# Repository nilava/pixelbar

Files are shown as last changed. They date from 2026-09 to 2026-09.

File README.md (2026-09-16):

# Pixelbar

An 8×24 WS2812B desk panel driven by an ESP32-C3, built as an open alternative
to a Busy Bar: it shows your status to the room, runs a focus timer, keeps the
time, and takes input from a rotary encoder, three hidden touch zones, and a
web page on your phone.

The panel is three 65 mm 8×8 WS2812B boards butted edge to edge inside a
snap-fit printed case, behind a per-LED light grid and a diffuser. It joins
your network through a setup network of its own, so nothing is compiled in and
no credential ever enters the source tree.

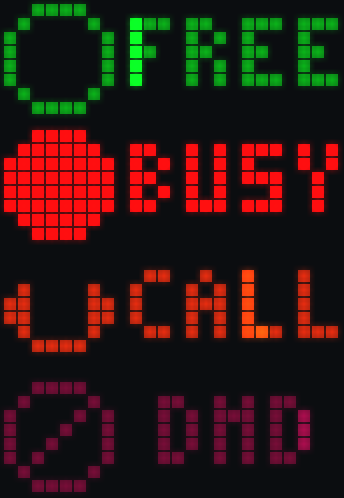
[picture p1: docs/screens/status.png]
status screens


## Status

**It works, on real hardware.** The panel runs at a measured 100 fps, joins
WiFi through its own setup portal, keeps the right time over SNTP, serves a web
page you can drive it from, and remembers everything you change across a power
cut. The encoder is wired and the whole screen tree is navigable from it.

| | |
| --- | --- |
| Display, input, screens, settings | done, on hardware |
| WiFi, setup portal, SNTP, web page | done, on hardware |
| LED output over SPI + GDMA | done — see *Why not RMT* below |
| Touch pads | written and host-tested; the TTP223s are not soldered yet |
| Accelerometer | not started; the MPU-6050 is not fitted |
| OTA, Mac mic-detect helper, Slack and calendar | not started |

28,807 assertions run on a laptop with no hardware and no ESP-IDF. The image is
at 49% of its 1.66 MB slot.

## Controls and screens

Three touch zones sit under the top edge, marked by printed dimples, and the
encoder knob is on the top edge at the right.

| Input | Action |
| --- | --- |
| Knob, turn | The value on this screen, or the view cycle at rest |
| Knob, press | Go in: open a menu entry, accept a value, claim a status |
| Knob, hold | Come back out, one level at a time |
| Knob, double-press | Straight back to the home view |
| Left zone, tap | FREE ↔ BUSY |
| Left zone, double-tap | CALL |
| Left zone, hold | CALL |
| Middle zone, tap | Start or pause the focus timer |
| Middle zone, hold | Reset the timer to its set length |
| Right zone, tap | Next view |
| Right zone, hold | DND on or off |
| Left and right together | Sleep or wake |
| Swipe across the zones | Next or previous view |

The four home views the knob cycles are **status**, **clock**, **timer** and
**scene**. The touch rows are written and tested but the pads are not soldered
yet, so today they are reachable only from the web page, which drives them as
pad *levels* rather than as events — the gesture recogniser sees exactly what a
finger would produce.

**Press goes in, hold comes out**, at every level. One rule the whole way down
means there is always a way back that does not depend on remembering how deep
you are. Turning the knob while pressing it used to adjust brightness from
anywhere; that is gone, because on a KY-040 the push switch shares its ground
with the rotary contacts, so an ordinary turn kept being read as the modifier
and the panel fought itself. Two gestures competing for one movement is worse
than one gesture and a menu.

A tap never waits to find out whether it is going to become a double tap:
holding it back for the 280 ms that would take puts the delay on the most-used
gesture on the device. The first tap fires at once and the second *supersedes*
it, which works because the actions behind them are assignments — BUSY, then
CALL — rather than steps.

Telling a chord from a swipe is the awkward one, because a finger dragged
across the pads lights two at once as well. Timing cannot separate them: for the
first hundred milliseconds a brisk swipe and a two-finger press are identical.
What separates them is that a chord is *held* and a drag is not.

The status words are each 23 px wide in the proportional font, so they sit
still and centred rather than scrolling. Anything wider than the panel scrolls
automatically.

An 8x8 icon, a one pixel gutter, and the label in a 3x5 mini font: exactly 24
columns, so a status word never scrolls. FREE is an open ring and BUSY is the
same ring filled in, which is what makes the change between them read as the
ring solidifying.

That layout has 15 columns for the word, and AWAY, FOCUS, LUNCH and MEET are
wider than that. Rather than scroll them, those statuses drop the icon and take
the whole panel as a **badge**: a filled field in the status colour with the
word cut out of it in black. Colour carries the meaning, so no picture is
needed, and it reads from much further away because the lit area is three times
larger. The two layouts turn over into each other without either knowing which
the other is.

The badge fill is held below full value on purpose. A full-width field lights
about 150 LEDs where the icon layout lights 48, and at full value the brighter
statuses draw past the 2500 mA cap — which the renderer would handle by scaling
*those statuses only*, so changing status would visibly change how bright the
panel is.

| | |
| --- | --- |
| boot | disk |
| free | call |
| focus | lunch |
| menu | status picker |
| timer | colour picker |

Holding the knob opens a menu, which scrolls like the view cycle does. The
status picker shows each status *as the panel would show it* rather than as a
row about it, so what you are scrolling through is a preview of what the room
will see.

Elements change in place rather than moving across the panel. A digit turns
over like the face of a counter wheel — both faces on screen for the whole
turn, the outgoing one foreshortening and riding away from the axis while the
incoming one rises into it, which is the projection of a cylinder and is drawn
as one. An icon and its label hand over by collapsing into themselves while the
next pair grows out of the same spot.

Everything moves. Icons breathe, CALL animates its handset and pulses harder
because it is the one status that must interrupt you, the clock's second hand
walks the panel's 60-pixel perimeter, timer digits roll, bars glide to their
targets, and the colour picker has a specular band travelling its ramp.

## Settings

The menu is the settings tree, scrolled like a record. Ten groups, and
everything the device stores or is paired with is reachable from the knob.

| Group | Settings |
| --- | --- |
| **STAT** | jumps straight to the status picker — a shortcut, not a group |
| **DISP** | brightness, accent hue, flip, sleep-after, current cap |
| **TIME** | work minutes, rest minutes, sets, auto-continue |
| **IDLE** | which ambient scene: solid, rainbow, plasma, sparkle |
| **TILT** | motion gestures on/off, lay-flat-to-sleep |
| **TAP** | touch lock |
| **CLCK** | 12 or 24 hour |
| **WIFI** | **IP** shows the address, **DROP** forgets the network |
| **HOST** | **ADD** opens a pairing window, **LIST** shows who is paired, **DROP** forgets them all |
| **PLAY** | the media remote — jumps straight to it, a shortcut not a group |
| **SYS** | **WIPE** — tokens, bonds and network, then a restart into setup |

DROP forgets one thing and WIPE forgets everything; the group says what the
thing is. Every one of them asks first, on a screen that opens on *no* — the
knob has no undo.

**PLAY** needs no software at all. The panel advertises a Bluetooth HID
service, so any Mac, iPhone, Windows or Linux machine can pair it as a media
remote from its own Bluetooth settings and never hear the name Pixelbar. On
that screen the knob is a volume dial, pressing it is play/pause, and the three
pads are previous, play/pause and next. The arcs beside the speaker are lit
only while something is actually listening — a volume dial connected to nothing
looks exactly like one that works.

**HOST** is the group worth knowing about. The panel is driven over HTTP by
hosts holding a token, and over Bluetooth by hosts that have bonded; **LIST**
is the one place the device says who those are, by the name each gave when it
paired. **SYS → WIPE** exists because the alternative was an authenticated
request from a host that was already paired — so a panel whose Mac had gone,
been re-imaged, or would not pair had no way back at all.

| | |
| --- | --- |
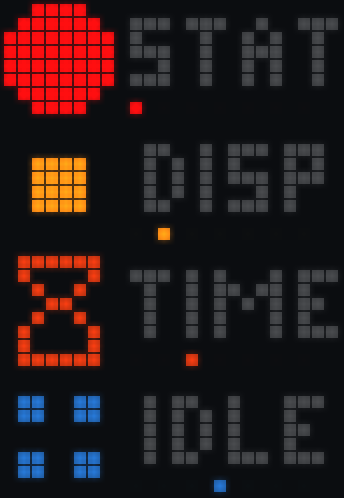
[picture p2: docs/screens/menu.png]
menu
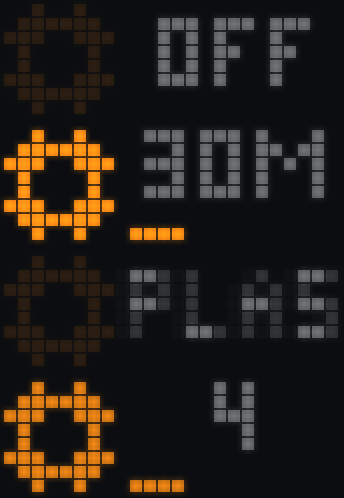
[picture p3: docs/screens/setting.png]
setting
|  |  |

A setting is a row in a table rather than a screen of its own: what it is
called, what it looks like, what kind of value it holds, and an id that one
get/set pair switches on. One generic screen serves toggles, numbers and
choices, because they differ by a few pixels and not by a layout — the value
arrives already rendered as `ON`, `25M` or `PLASMA`, so the drawing layer never
learns what any setting *means*.

Everything is one versioned struct in a single NVS blob: one atomic write, and
a migration is a version check instead of forty defaulted lookups. It is
written once the knob stops moving rather than once per detent.

## Network and setup

Nothing is compiled in. With no credentials stored the device brings up an open
`PIXELBAR-XXXX` network and a captive portal; join it and the setup page opens
by itself.

That last part is two pieces working together. A DNS responder answers every
query with the device's own address, so the phone's connectivity check —
`captive.apple.com`, `connectivitycheck.gstatic.com` — resolves to us; and a
404 handler redirects, which is what the phone recognises as a portal rather
than an internet. Sixty lines of socket code, because the only query worth
parsing is one we have already decided the answer to.

Credentials are stored **only once they have worked**. The device tries them
over the station half of an APSTA mode while the portal is still up, so a typo
is reported back to the page instead of being persisted and locking the device
out of its own setup on the next boot. If a stored network then becomes
unreachable for six attempts — you moved house, the password changed — the
setup network comes back, because the web page needs a network and the panel
cannot type a password.

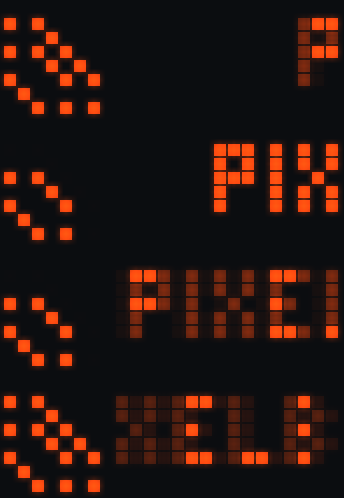
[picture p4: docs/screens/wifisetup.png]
wifi setup


The panel says which of the three it is doing: the network to join, the network
being tried, or the address to visit. All three are one layout — a signal mark
and a marquee — separated by colour and by how fast the arcs climb.

Time comes from SNTP once there is an address. Before the first sync the clock
shows `--:--` rather than midnight: a clock that is confidently wrong is worse
than one that admits it is waiting.

## The web page

One self-contained HTML file, gzipped at build time and linked into the image.
It cannot live in a filesystem partition — the partition table already spends
3.5 MB of a 4 MB part on two OTA slots.

It emulates the touch pads and the knob, sets status and brightness directly,
runs the WiFi setup, and shows what the panel is showing.

```
GET    /                     the page
GET    /api/state            screen, status, timer, brightness, fps, clock
POST   /api/input            pads as levels, knob detents, status, brightness
POST   /api/display/draw     show something; see below
DELETE /api/display/draw     stop showing it
POST   /api/ota              a firmware image; the panel restarts itself
GET    /api/screen           what the panel is showing, as hex RGB
GET    /api/wifi/scan        nearby networks
GET    /api/wifi/status
POST   /api/wifi/connect     {"ssid": "...", "pass": "..."}
POST   /api/wifi/forget
```

### Watching it from elsewhere

`GET /api/screen` returns the framebuffer as 192 hex RGB triples, and the web
page draws it into a canvas about ten times a second. This panel was debugged
by photograph three times in one evening; that is what it is for.

They are the framebuffer's own colours, before gamma and the current cap —
what the screen *means* rather than what the LEDs receive. The wire bytes are
already covered by the preview tool and the map test.

### Showing something

One endpoint for everything a host wants to put on the panel — a build result,
a doorbell, the meeting you are about to be late for.

```bash
curl -X POST http://<panel>/api/display/draw -d '{
  "source":   "ci",            # equal priority from a different source replaces
  "text":     "BUILD PASSED",  # scrolls when it does not fit
  "icon":     "free",          # one of the built-in icons, by name
  "priority": 50,              # 10 ambient, 50 notification, 90 urgent
  "ttl":      10,              # seconds; 0 means until something replaces it
  "color":    "#00D246"
}'
```

`"until": <unix seconds>` counts down to a moment rather than for a duration —
a duration is already stale by however long the request took to arrive. A
payload that is still counting outlives its `ttl`, because something counting
down to a moment should not vanish before the moment arrives. With no clock
yet, no countdown is drawn rather than a wrong one.

Text and a countdown **take turns** rather than sharing the panel. The mini
font is five rows tall and so is the time face, which is ten rows in a panel
eight rows high; shrinking either to fit makes both harder to read than showing
one at a time.

A request is accepted when it is at least as important as what is already
showing, so a build notification cannot push a call off the panel. Pairing and
a firmware update outrank every request — those are states the device is in,
not things a host asked for.

Nothing here touches the model. An HTTP handler runs on the server's task and
the model runs on the render loop; the only thing that crosses between them is
a four-byte command through a FreeRTOS queue that the loop drains at the top
of a frame. A handler reaching into the model would be mutating state halfway
through a frame already being drawn from it, and the failure would be a rare
torn frame rather than anything a test would catch.

### Pairing

**Changing anything needs a token; reading never does.**

Reads — `GET /api/state`, `GET /api/screen` — return what the panel is already
showing to the room, and guarding them would be protecting a secret painted on
the wall. Writes need `X-API-Token`, and that includes `POST /api/ota`, which
is arbitrary code execution on the device.

To get one, ask the panel and read it:

```bash
curl -X POST http://<panel>/api/pair/begin      # the panel shows six digits
curl -X POST http://<panel>/api/pair -d '{"code":123456}'
# {"token":"…32 hex characters…"}
```

The code is generated on the device, exists nowhere else, lives for sixty
seconds, is spent on first use, and gives you three attempts. It is the same
ceremony Bluetooth uses and deliberately so — one pairing gesture whichever
transport is carrying it, rather than two unrelated ones. The token is kept in
NVS and survives a reboot and an update.

**Setup mode is exempt.** The device is then its own isolated network with one
client slot and nothing else on it to reach, and a device nobody can provision
is worse than one anybody already on it can poke.

**This is a token over plain HTTP, not TLS**, and the README should keep saying
so. A certificate store, a clock that must be right before anything works and a
64 KB bundle would buy protection against an attacker already inside the
network — who could unplug it instead. What a token stops is the casual and the
accidental: a script pointed at the wrong address, a housemate who found the
web page. That is the actual threat to a desk ornament.

## Transitions

The motion is semantic: it tells you what kind of move just happened.

| | |
| --- | --- |
| disk | ignite |

| Gesture | Motion |
| --- | --- |
| Moving through the view cycle | The panel turns like a record |
| Opening an adjust screen | Wipes up, like a drawer |
| A status change | The new colour bursts out of the icon and is drawn back into it |
| Sleeping or waking | Fades through black |

The timer finishing is the moment the device exists for, so it takes the whole
panel: one frame of white, a quarter-second settle into the status colour with
the tick drawing itself on, about a second held with a highlight crossing, then
a fade that *uncovers* what was underneath rather than painting over it. Any
input gets you out of it — a celebration you have to sit through is an
obstacle.

done

Nothing slides. The panel is read as a radial strip of a disk — column 0 at the
hub, column 23 at the rim — so content printed on it advances through the same
*angle* at every radius and therefore a different *distance*. The rim end whips
past while the hub end crawls, and a glyph shears as it goes because its left
edge is moving slower than its right. A slide moves every column by the same
amount, which at 24 columns reads as pixels being moved rather than an object
turning.

A status change is not a transition at all but an event: a front of the new
colour bursts out of the icon with a white-hot leading edge, floods the panel,
and is then drawn back in — and what it uncovers is the new screen. It lands on
the icon, because that is where it came from.

Both screens keep animating for the whole move, and the outgoing one is drawn
with the state it had when the move began, so a status change animates from the
old word into the new one rather than flipping instantly.

## What makes it smooth

More animation on its own would have looked stepped, because the pipeline
quantised motion in six separate places. Fixing those was most of the work.

| Was | Now |
| --- | --- |
| 62.5 fps, from `pdMS_TO_TICKS(1000/60)` truncating to 16 | 100 fps, which divides the 1 kHz tick exactly |
| `dt` rounded to 1 ms | microseconds, so a 10 ms frame is not quantised by 10% |
| Text jumped a whole LED every 83 ms | sub-pixel, the boundary LED lights partially |
| Bars snapped to 24 positions | anti-aliased, continuous at any fraction |
| Gamma table stopped at 236 | reaches 255, recovering the top 7.5% of range |
| ~44 brightness levels, so a 4 s fade held each for 9 frames | temporal dithering carries the remainder between frames |
| Output blocked the loop for 5.8 ms | queued, so the next frame draws while it clocks out |

The ESP32-C3 has no FPU, so `sinf` is emulated in software and plasma alone
wanted 576 of them per frame. Trigonometry is a 256-entry table.

## Hardware

| Part | Notes |
| --- | --- |
| 3 × 8×8 WS2812B matrix | 65 mm boards, 8 mm pitch, chained left to right |
| ESP32-C3 SuperMini | USB Serial/JTAG, so GPIO20/21 are free |
| 7Semi USB-C breakout | 5 V in, separate from the ESP32's own port |
| 3 × TTP223 (HW-763) | touch zones, sensing through 1.5 mm of the case wall |
| MPU-6050 (GY-521) | tap and orientation |
| EC11 encoder | bare, behind the top wall, knob on the top edge |
| 1N5819, 330 Ω, 1000 µF | back-feed block, data series resistor, bulk cap |

The GPIO map, the power wiring and the physical placement are in
[`hardware/WIRING.md`](hardware/WIRING.md), alongside the parametric enclosure
model and its interference audit.

```
hardware/WIRING.md                             # pin map, power, placement
hardware/enclosure/ws2812b_8x24_enclosure.py   # the model; edit params, re-run
hardware/enclosure/check.py                    # 16 interference + clearance checks
hardware/enclosure/fit_test.py                 # corner coupons for a test print
hardware/enclosure/render.py                   # the mesh renderer behind hardware/img
hardware/stl/                                  # tray.stl, grid.stl and the coupons
```

| | |
| --- | --- |
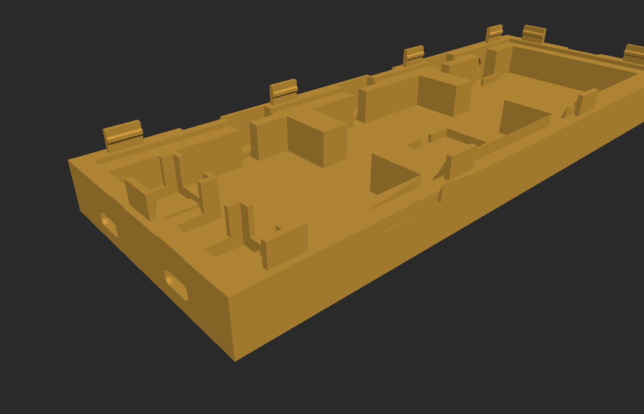
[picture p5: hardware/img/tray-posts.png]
tray posts
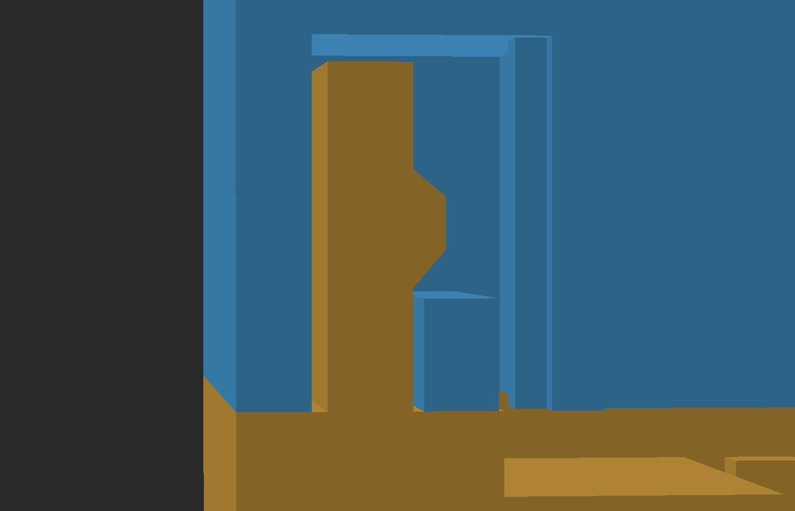
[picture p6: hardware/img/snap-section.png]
snap section
|  |  |

The snap closure is rigid posts on the tray meeting spring beams inside the
frame. The beams flex **in the print plane**, so nothing relies on the strength
of a layer bond — printing the parts flat would otherwise snap the hooks off the
first time you closed the case.

## Firmware quick start

Needs ESP-IDF v5.3 or newer. Nothing else: there are no managed components to
download, so it builds offline.

```bash
. $HOME/esp/esp-idf/export.sh
cd firmware
idf.py set-target esp32c3
idf.py build
idf.py -p /dev/cu.usbmodem* flash monitor
```

There is no configuration step and no credentials file to create. On first boot
the panel shows a network name — join it from your phone, pick your WiFi, and
the setup page closes itself when the panel shows you its address.

> **Why there is no `secrets.h`.** There used to be, and it was quietly
> leaking. A password written into a header does not stay in the header: it
> ends up in the object file, the static library, the `.elf` and the `.bin`, so
> an ordinary build tree becomes five more copies of a secret nobody thinks of
> as holding one. No firmware source has ever seen a credential now, which is
> the only way to be certain no build artifact has either.

If the USB Serial/JTAG port stops enumerating mid-session — it happens on these
boards — unplug and replug the cable. Note that driving DTR/RTS on an ESP32-C3
selects download mode, so a naive serial reader can park the board at *waiting
for download*; read the port without touching those lines.

## The LED mapping

How the LEDs are wired *inside* one 8×8 board varies between suppliers, so it
is a config value rather than an assumption. For this panel it is settled,
taken from a WLED setup running on the same hardware:

| WLED | `kWiring` |
| --- | --- |
| 1st LED: Top / Left | `Corner::TopLeft` |
| Orientation: Horizontal | `Axis::Row` |
| Serpentine: unchecked | `serpentine = false` |
| Panel offsets X = 0, 8, 16 | `chainRightToLeft = false` |

The boards are **progressive, not serpentine**: every row runs left to right
and the chain drops back to the left at the end of each one. The original guess
here was serpentine, which is true of many 65 mm boards and not of these.

For a different panel, `Pattern::MapTest` is still there — set `kMapTestSeconds`
in `firmware/main/main.cpp` and watch:

- a **red** pixel marks logical (0,0), the top-left corner
- a **white** pixel walks the panel in logical order
- **green** pixels on the bottom row mark the seams between boards

The white pixel should sweep left to right along the top row, then drop to the
next. All sixteen combinations are covered by the tests, so any setting you pick
is guaranteed to address all 192 LEDs exactly once.

## Tests and preview, no hardware needed

The whole drawing layer **and** the input and state layer are free of ESP-IDF,
so they build and run on a laptop with a plain C++17 compiler. That portability
is load-bearing rather than incidental: the gesture recogniser and the state
machine are the two things most worth testing and the two things least
pleasant to test on hardware, so they sit behind an interface (`ui::Ports`)
that the device implements with GPIO and NVS and the simulator implements in
memory. 28,807 assertions run in a few seconds.

```bash
./test/run.sh                                    # builds and runs the tests
./test/sim.sh                                    # drive the panel from your keyboard
./build-host/preview docs/preview docs/screens   # still sheets
python3 tools/ppm2png.py docs/preview
python3 tools/ppm2png.py docs/screens

./build-host/preview --anim docs/anim            # animated clips
python3 tools/ppm2gif.py docs/anim               # needs Pillow
```

A still image cannot show whether motion is smooth, so the animation is
verified by watching the GIFs rather than by reading a description of them.

`./test/sim.sh` goes further: it runs the real state machine, the real gesture
recogniser and the real renderer at 100 fps in your terminal, and lets you drive
them from the keyboard — `a s d` tap the pads, `A S D` hold them, `e` swipes,
`, .` turn the knob, space presses it, `f` lays the panel flat. Keys become raw
pad levels and encoder counts rather than events, so the recogniser is exercised
for real: a tap is a pad going down and coming back up over several frames, and
a swipe is a drag with the overlaps a finger actually makes.

It draws out of the same GRB wire bytes that would go down the data line,
through the same LED mapping and gamma table, so a mapping or gamma mistake
shows up there rather than on a soldered panel. `./build-host/sim --selftest`
runs a scripted sequence with no terminal, for when you want it in a pipe.

The preview reads back the same GRB bytes that would go out on the wire,
through the same mapping, so a gamma or mapping mistake shows up on screen
instead of on a soldered panel.

| | |
| --- | --- |
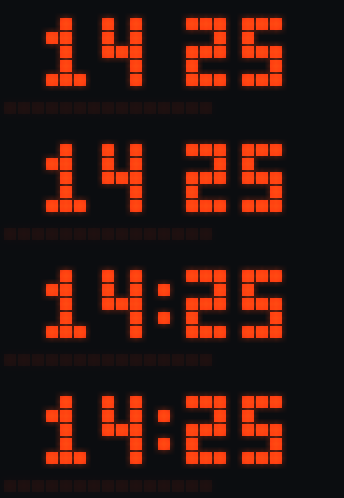
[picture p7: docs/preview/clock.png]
clock
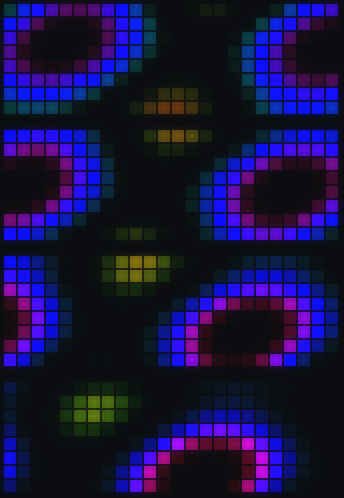
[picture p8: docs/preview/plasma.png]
plasma
|  |  |

The ambient patterns are still there as a screensaver.

## Power

192 LEDs at full white would draw about 11 A, which no USB-C supply will give
you. `Framebuffer::render` estimates the draw of every frame and scales it to
stay under a budget the caller passes in. The cap is enforced in the render
path, not in the patterns, so nothing drawn can exceed it.

The budget is a setting rather than a constant, because the panel has to be
right on both the supply it is developed on and the one it ships against:
2500 mA through the USB-C breakout from a 3 A source, and 1900 mA from the 2 A
brick on the bench. Nothing in the drawing layer is tuned to one number — the
heavy frames, a full-width status badge and the completion flash, are held
under 2300 mA so that at the design target they never trip the cap at all,
which is what keeps brightness consistent when you switch between screens. On
the smaller supply the cap does engage, but not until about 85% brightness.

The per-LED figure is 60 mA, the datasheet's three channels at 20. WLED uses a
measured 55 for the same part, so this runs about 9% pessimistic — the right
direction to be wrong in for a current estimate.

## Layout

```
firmware/components/panel/   framebuffer, mapping, fonts, icons, patterns,
                             screens, transitions, animation (no IDF deps)
firmware/components/ws2812/  WS2812B over RMT, no external components
firmware/main/               app_main, GPIO map
test/                        host-side tests
tools/                       PNG preview renderer
hardware/                    enclosure model, STLs, wiring
```

## Documentation

| | |
| --- | --- |
| [docs/ARCHITECTURE.md](docs/ARCHITECTURE.md) | how the firmware is arranged and why — the C3's missing peripherals, the SPI output path, dithering, the disk geometry, the navigation contracts |
| [hardware/WIRING.md](hardware/WIRING.md) | the GPIO map, the encoder's pull-ups, power, the panel chain |
| [CONTRIBUTING.md](CONTRIBUTING.md) | the constraints the build enforces |

## License

MIT, see `LICENSE`.

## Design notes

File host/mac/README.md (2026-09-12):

# Pixelbar Mac helper

A menu-bar agent that sets the panel's status from what your Mac is doing.

| It notices | The panel shows |
| --- | --- |
| Microphone in use | `BUSY` |
| Camera in use | `CALL` — video beats audio, because it is the more useful thing to tell the room |
| Both idle again | whatever it was showing before, not `FREE` |

That last row is the one worth explaining. If you set `LUNCH` by hand and a
notification chime opens the microphone for two seconds, restoring to `FREE`
would quietly undo you. The helper remembers what it displaced and puts that
back.

## Build and install

```bash
make            # builds Pixelbar.app here
make run        # runs it without installing
make install    # copies to ~/Applications and starts it at login
make uninstall
```

No Xcode project, no developer account, no certificate. `swiftc`, `make`, and a
Mac — nothing else. `~/Applications` rather than `/Applications` because it
needs no admin rights and belongs to one user.

The build does **ad-hoc sign** the bundle, and that is not about distribution.
macOS attributes the Local Network permission to a code identity, and `swiftc`
leaves a linker-signed binary whose identifier is `Pixelbar` rather than the
bundle id — which TCC cannot hold a durable grant against. The symptom is
precise and thoroughly misleading: **discovery finds nothing when launchd
starts the app at login, and the identical binary works when you run it from a
terminal**, because there it inherits the terminal's own permission. Signing
with `--identifier com.pixelbar.helper` is the fix, and it needs no account.

On first launch it **finds the panel by itself**. There is nothing to type.

If it cannot — and there are networks where it cannot — **Find panel** retries
and reports what happened, and **Panel address…** still takes one by hand.

## Permissions

**None.** It never asks for microphone or camera access, and could not use them
if it had them.

The distinction is the whole reason this approach is worth having: CoreAudio's
`kAudioDevicePropertyDeviceIsRunningSomewhere` answers *is some process running
this device*, which is a different question from *what is that process
recording*. A helper that had to request microphone access in order to notice
the microphone was busy would be a worse trade than the feature is worth.

## Your calendar

**Off by default** — reading somebody's calendar is a thing to opt into, not a
thing to discover has been happening. Switch on **Calendar sets MEET**.

| When | What happens |
| --- | --- |
| A meeting starts in the next ten minutes | its title scrolls on the panel with a live countdown |
| A meeting is running | the panel shows `MEET` |
| Your microphone or camera is live | that wins — see below |

It reads through **EventKit**, which means whatever accounts Calendar.app
already has: iCloud, Google, Exchange, a subscribed ICS. No OAuth client, no
consent screen, no client secret in a repo, no refresh token to expire at the
worst possible moment. One permission prompt on first run, and it works offline
against the local store. The cost is that an account not added to Calendar.app
is invisible here — a fair trade for not implementing an identity provider
inside a desk ornament.

**The sensors outrank the calendar**, in this order: camera → `CALL`,
microphone → `BUSY`, meeting in progress → `MEET`. That ordering is by how
directly each thing is observed. A live camera is happening now; a calendar
entry is somebody's earlier intention, and people leave early, join late, and
decline by walking away.

Declined invitations are skipped, all-day events are ignored, and a meeting is
announced only in its last ten minutes — earlier than that it is not news, and
a panel showing the same meeting for an hour is a panel nobody looks at. The
announcement is sent once per meeting rather than on every poll, because
re-sending would restart the scroll.

An event counts as a video call if a known joining host appears in its URL,
location or notes — Meet, Zoom, Teams, Webex, Whereby, Jitsi. Deliberately a
short list rather than any URL: "there is a link in the notes" is true of most
meetings and means nothing.

## Two ways to reach the panel

**Wi-Fi first, Bluetooth second.** Not really a preference — an ordering by
capability. Wi-Fi is the pipe that also carries firmware images and the web
page, so when it is there it is the one to use. Bluetooth needs no credentials,
no router, no address and no discovery at all, which is exactly the situation
in which it is the only one left: a panel that has never been provisioned, or
one whose network is down, or a network that blocks traffic between two clients.

The menu says which one is carrying commands.

Both speak the same JSON. A write to the Bluetooth command characteristic and a
`POST /api/input` are the same input in the same words, parsed by the same
function on the device — two transports that disagreed slightly about what a
command meant would be a bug nobody finds until the day one of them is all
there is.

## Setting it up

**Open the window.** Setup is a window with every step on it, not a chain of
dialogs — finding the panel, pairing, scanning, joining, collecting the token —
with the current one named and the rest greyed. Each of those steps takes real
time (a scan is two seconds, a join can be ten), and a process that goes quiet
for half a minute reads as broken even when it is working perfectly. The network
picker is part of the window rather than an alert on top of it, because choosing
a network is a step of setup and not an interruption to it.

**One code, both transports.** The passkey secures the Bluetooth link, and the
panel hands back a Wi-Fi token across that same link. There is no second
ceremony — asking again on the second transport would be asking the same
question twice and calling it security.

**Reset everything** is in the same window. It tells the panel to forget every
paired client, every Bluetooth bond and its network, and restarts it into setup;
this Mac forgets its token and the panel's address. You must also forget the
panel in **System Settings → Bluetooth**: macOS keeps its half of the pairing
keys and will not offer the code again until it does.

The menu shows one thing until it is paired, and a first line that says which
part is missing: no panel found, not paired, or paired but unreachable. Three
different problems with three different remedies, rather than greyed-out options
with no explanation. Until setup is done the helper sends nothing, so an unpaired
helper is idle rather than silently failing every time a microphone opens.

## Bluetooth pairing

**The panel shows a six-digit code and macOS asks you to type it.**

That is not ceremony. Without it, anything within about ten metres could drive
the panel — a different and worse posture than the HTTP API, because a home LAN
at least has a door on it. Bluetooth's own answer to this is "Just Works"
bonding, which encrypts the link against eavesdroppers and authenticates
nobody: anything in range can bond, and is then trusted for good.

A passkey fixes the half that matters. The code is generated on the device from
its hardware random number generator, exists nowhere else, and is displayed on
a panel you have to be looking at — so a host that can produce it is a host in
the room. The command characteristic requires an authenticated link, so there
is no way to drive the panel without having done this once.

Use **Pair over Bluetooth…** from the menu. It is deliberate rather than
automatic because the alternative is being asked to read six digits off a panel
at whatever moment your microphone first happens to open.

Reading the panel's state needs an encrypted link but not an authenticated one:
what it returns is what the panel is already showing the room, and charging a
pairing prompt to keep a secret that is painted on the wall would be theatre.

A host that bonded before and comes back with new keys — a Mac that was
re-imaged, say — is re-paired rather than refused, because the alternative is a
device nobody can reconnect to and nothing on it to clear the old bond from.

## How it finds the panel

Two ways, in this order, because neither works everywhere.

**A UDP broadcast probe** on port 51737. The panel answers with its name and
address. One packet out, one back; measured at about a second on a home
network, nearly all of which is the window held open in case a second panel
answers.

**A sweep of the local /24** if nothing replies. Some networks drop broadcast
between clients — "AP isolation", common on guest and mesh setups — and on
those the probe goes nowhere. Asking all 254 addresses for `/api/state` is
crude, and it works where broadcast does not. Measured at about nine seconds,
which is a fine price for a fallback and a poor one for a default, so it only
runs when the probe finds nothing.

More than one panel produces a chooser rather than a silent pick, because
picking silently would be picking wrongly half the time.

> **Why not mDNS?** It is the obvious answer and it costs more than it looks.
> mDNS is a managed component in ESP-IDF 5.x, and pulling it in would break the
> firmware's promise that it builds offline with nothing to download. A correct
> responder is also considerably more than this — PTR, SRV, TXT and A records,
> name conflict resolution, and politeness toward every other responder on the
> segment — to answer one question asked by one helper. The device already runs
> a hand-written DNS responder for its setup portal, so a second datagram
> handler was about fifty lines against a dependency.

## How it watches

The microphone is a **property listener**, not a poll — CoreAudio calls the
helper when the state changes, so a call starting is noticed at once and a
quiet afternoon costs nothing.

Only devices with input channels are watched. Without that filter your speakers
and your monitor count as audio devices that are "running" whenever anything
plays a sound, and a notification chime would look like a conference call.

The camera has no equivalent notification, so it is polled every five seconds —
which is fine, because a camera is nearly always on *because* the microphone
already is, and the microphone is the fast path.

**Two seconds of quiet** are required before the panel is handed back. Some
conferencing apps close the microphone between sentences, and a panel flicking
between `BUSY` and `FREE` would be worse than one that lags a little.

## The menu

- **Pause** — stop touching the panel, and hand back whatever was displaced.
- **Microphone sets BUSY** / **Camera sets CALL** — either rule, off.
- **Set status** — all eight, by hand, for the things no sensor knows about.
- The first line reads `Watching`, `Showing Busy`, `Paused`, or
  `Panel unreachable`.

## If the panel is unreachable

Nothing happens, loudly enough to see in the menu and quietly enough to ignore.
Requests time out in two seconds; a gadget that is switched off is an ordinary
condition, not an error worth a dialog.

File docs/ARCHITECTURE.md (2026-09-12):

# Architecture

How the firmware is arranged, and why. Most of what follows is a constraint of
the ESP32-C3 rather than a preference — this chip is missing several things the
obvious design would have used.

## What the chip does not have

| Missing | Consequence |
| --- | --- |
| **FPU** | `sinf` is emulated in software. Plasma alone wanted 576 of them per frame, so trigonometry is a 256-entry table. |
| **PCNT** | No hardware quadrature counter. The encoder is decoded in a GPIO interrupt on both edges of A and B, running a four-state table into an atomic `int32_t`. |
| **Touch peripheral** | Hence external TTP223 modules rather than capacitive pins. |
| **RMT DMA** | `SOC_RMT_SUPPORT_DMA` is defined for the S3 and absent here. See below — this one changed the whole output path. |

## Components

```
firmware/components/panel/   drawing.       IDF-free.
firmware/components/ui/      events, gestures, state, settings. IDF-free.
firmware/components/board/   GPIO, the encoder ISR, NVS.  IDF only.
firmware/components/net/     WiFi, portal, SNTP, HTTP.    IDF only.
firmware/components/ws2812/  the LED driver.              IDF only.
firmware/main/               wiring, and the render loop.
tools/sim.cpp                the terminal simulator.
```

`panel` and `ui` contain no ESP-IDF header. That is load-bearing: `test/run.sh`
compiles both with plain `g++` and runs 28,807 assertions with no toolchain and
no hardware, and those two layers are the ones most worth testing.

Everything needing a peripheral sits behind `ui::Ports` — a small abstract
struct with `read_raw`, `load_settings`/`save_settings`, `wall_clock`,
`wifi_connected` and `net_mode`. `board` implements it on the device; the
simulator implements it in memory.

> `board` is not called `hal`. ESP-IDF already has a component of that name, and
> a second one shadows its headers until `mbedtls` cannot find `sha_types.h`.

`net` deliberately does **not** `REQUIRES panel ui`. An HTTP handler runs on the
server's task and the model runs on the render loop; the only thing crossing
between them is a four-byte command through a FreeRTOS queue, drained at the
top of a frame. If someone later includes a model header there, that CMake line
is what fails.

## Why the LED output is SPI, not RMT

RMT is the obvious peripheral for WS2812B and it is the wrong one on this chip.
Without DMA it is refilled from an interrupt: 192 LEDs × 24 bits = 4,608 symbols
per frame, refilled 48 at a time, so **96 interrupts per frame, 9,600 a second**
at 100 fps, each with about 58 µs of runway. A WS2812B latches after roughly
50 µs of idle line, so one late refill latches a partial frame and restarts at
LED 0.

On the bench that was a flicker travelling along the panel, worse while the
encoder was being turned — the GPIO interrupt decoding it was competing for the
same microseconds. Widening the buffer and raising the interrupt priority made
the race easier to win. It did not stop it being a race, and WiFi is far less
polite than an encoder: `nvs_commit()` and `esp_ota_write()` disable the flash
cache for milliseconds at a time, while the ISR lives in flash. Saving a setting
would tear the panel.

So the deadline had to stop existing rather than get easier. **SPI2 + GDMA**:
four SPI bits per WS2812 bit at 3.2 MHz is exactly 1.25 µs per bit.

```
0 -> 1000    312 ns high, 937 ns low   (T0H spec 220-380 ns)
1 -> 1110    937 ns high, 312 ns low   (T1H spec 580-1000 ns)
```

The reset gap is more zero bytes on the end: 112 of them hold the line low for
280 µs. Once queued, DMA clocks the whole frame out of SRAM with no CPU and no
interrupt-latency exposure anywhere in it. Cost: the wire buffer grows from 576
to 2,416 bytes.

## Temporal dithering, and its one hard edge

At low brightness the gamma curve leaves only about 44 distinct levels, so a
four-second fade holds each for nine frames and visibly steps. A sigma-delta
error term carried between frames recovers the intermediate values.

It has a floor, and the floor is not a matter of taste. **The pulse rate is the
value**: a pixel at 1/8 of a level lights one frame in eight. Below roughly
30 Hz those pulses stop fusing and you see individual flashes. There is a hard
cutoff at `kDitherKnee = 256 * 30 / kFramesPerSecond` — below it the output is
zero and the error is cleared.

Three things were tried first and are worth recording because each seemed
obviously right:

- **Jitter alone** made the flicker less tonal but no less visible.
- **Jitter on dark pixels** produced stray lit LEDs — 132 strays over 600 frames.
- **A smooth roll-off made it worse**, dropping the pulse rate from 4.7 Hz to
  0.4 Hz. A rarer pulse is *more* noticeable, not less.

One more: the jitter value is shared across all three channels of a pixel.
Per-channel jitter meant the channels crossed the threshold on different frames,
so 50 frames in 600 had only one channel lit — a visible hue shift on what
should have been a neutral dim grey.

## The disk

The panel is read as a radial strip of a record: column 0 at the hub, column 23
at the rim. Content advances through the same *angle* at every radius and
therefore a different *distance*, so the rim end whips past while the hub end
crawls, and a glyph shears as it goes.

`blit_disk(dst, src, turn, gain_hub, gain_rim)` applies a vertical shear
proportional to radius, `dy(x) = turn * (kDiskHubRadius + x)`. The constants
matter: with a hub radius of 5 and a clear turn of 0.29 the hub moved only 1.4
rows and the whole thing read as a cross-fade. Hub radius 3 and a turn of 0.85
is what makes it read as rotation.

## Navigation

An explicit stack of depth four: Home → Menu → Group → Setting. Press goes in,
hold comes out.

Two contract details that cost an evening each if you get them wrong:

**Going back needs its own direction.** `kind_for(from, to)` is a pure function
of the pair, so Home→Menu and Menu→Home resolve identically. Each stack frame
records the kind it was pushed with and `pop()` plays the inverse, which makes
back-navigation correct by construction for any screen added later.

**The outgoing screen must be drawn with the state it had when the move began.**
`ScreenManager` used to snapshot the state lazily on the first transition frame,
but every caller mutates it *before* calling `go_to` — so the outgoing screen was
drawn with the incoming state. `go_to` and `restart_with` now take the outgoing
`UiState` explicitly. Reverting that makes 28 assertions fail.

**Model-side timers accumulate `dt`; they never compare against an absolute `t`.**
Otherwise pausing or time-dilating the simulator stretches the transitions but
not the timeouts.

## The encoder, and its shared ground

On a KY-040 breakout the push switch shares its ground net with the rotary
contacts, so turning the knob disturbs the switch line. Two guards, both of
which exist because of that and not because a switch needs them:

- The switch is **not read at all while the knob is moving**. A longer debounce
  cannot work: during a fast turn the contacts make and break continuously, so
  the disturbance lasts as long as the turning does.
- A contact shorter than 30 ms is not a press. The guard above only arms once a
  detent has been *decoded*, and a detent is four quadrature edges — tens of
  milliseconds after the knob really started moving, by which time a coupled dip
  has already latched and released. Nothing that looks backwards can fix that.
  What separates a finger from a bounce is duration, and since `Press` is
  emitted on release, the check costs no latency.

Both are mitigations for a wiring fault. See [WIRING.md](../hardware/WIRING.md):
the real fix is 10 kΩ pull-ups on `A`, `B` and `SW`.

An illegal quadrature transition — both lines changing between samples — is
counted and **not** used to discard the quarter-steps before it. Discarding them
was tried and was wrong twice over: it did not address the noise it was aimed at
(that drift produces perfectly legal Gray code), and at speed an illegal
transition means a *missed edge*, so throwing away three quarter-steps loses a
detent the user actually turned.

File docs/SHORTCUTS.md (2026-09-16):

# Pixelbar from your phone

There is no app, and there is not going to be one. iOS Shortcuts can send an
HTTP request, the panel has an HTTP API, and an app would need a developer
account to survive more than seven days on your own phone.

So the phone talks to the panel the same way the Mac helper does: a POST with
an `X-API-Token` header. What Shortcuts adds is *triggers* — an NFC tag on your
desk, a Focus mode turning on, a time of day, a button on your Home Screen.

> Shortcuts cannot speak Bluetooth GATT, so this is the Wi-Fi path only. On a
> network with client isolation — many office and guest networks — your phone
> cannot reach the panel at all, and nothing here will work. That is the case
> Bluetooth exists for, and it is the Mac helper's job.

## Get a token

One per device, so you can revoke the phone without disturbing the Mac.

1. On the panel: hold the knob → **HOST** → **ADD**. A six-digit code appears.
2. Open `http://<panel-address>/` on the phone, enter the code, and give it a
   name. You get a 32-character token back.
3. The panel's address is on **WIFI → IP**, and the paired list is
   **HOST → LIST**.

Keep the token somewhere the Shortcut can read it. A text field in the Shortcut
itself is fine for a device you carry; it is not a password to anything else,
and **HOST → DROP** on the panel revokes every one of them.

## The one Shortcut everything else is a variation of

**Get Contents of URL**

| Field | Value |
| --- | --- |
| URL | `http://192.168.68.105/api/input` |
| Method | `POST` |
| Headers | `X-API-Token` → your token |
| Request Body | JSON |
| JSON | `status` (Number) → `1` |

That is a whole recipe. Everything below changes the body.

## Set a status

`POST /api/input` with `{"status": n}`:

| n | Status | n | Status |
| --- | --- | --- | --- |
| 0 | FREE | 4 | AWAY |
| 1 | BUSY | 5 | FOCUS |
| 2 | CALL | 6 | LUNCH |
| 3 | DND | 7 | MEET |

**From a Focus mode.** Settings → Focus → *Do Not Disturb* → Add Automation →
Run Shortcut. One Shortcut sets `3`, and the "when Focus ends" one sets `0`.
This is the single most useful thing on this page: the panel then tells the
room what your phone already knows.

**From an NFC tag.** A sticker on the edge of your desk. Automation → NFC →
Scan. Tap to go BUSY on the way into a call, tap again on the way out — one
tag, with an *If* on the current status if you want it to toggle:

```
Get Contents of URL   http://<panel>/api/state        (GET, no token needed)
Get Dictionary Value  status
If  status  is  BUSY
    …POST {"status": 0}
Otherwise
    …POST {"status": 1}
```

Reads need no token, which is what makes that first step work.

## Put something on the panel

`POST /api/display/draw` — text, an icon, a countdown, a progress rail, or any
combination.

```json
{"text": "STANDUP", "icon": "timer", "ttl": 30, "color": "#FF8A1F"}
```

| Field | Meaning |
| --- | --- |
| `text` | up to 47 characters; it scrolls if it does not fit |
| `icon` | `free` `busy` `dnd` `moon` `sun` `timer` `gear` `grid` `display` `hand` `motion` `lock` `cross` `warning` `download` `info` `palette` |
| `color` | `#RRGGBB` |
| `ttl` | seconds; `0` means until something replaces it |
| `until` | a Unix timestamp — draws a **countdown** to it |
| `bar` | `0`–`100`, draws a progress rail |
| `priority` | `1`–`100`, default `50` |
| `source` | who is asking; the same source replaces rather than stacks |

`DELETE /api/display/draw` takes it away again.

**A countdown to your next meeting.** Shortcuts can read your calendar, so this
needs no permissions the phone has not already granted:

```
Find Calendar Events  where Start Date is after Current Date, limit 1
Format Date           <Start Date>  as Unix timestamp
Get Contents of URL   POST /api/display/draw
                      {"text": <Title>, "until": <timestamp>, "icon": "timer"}
```

**A leave-now alarm.** Run it at 17:25 on weekdays:

```json
{"text": "TRAIN", "until": 1789012345, "color": "#40C4FF", "priority": 80}
```

`priority` is what decides between two things wanting the panel at once. A
status claim is 50; anything above that wins.

## Drive the panel itself

`POST /api/input` also carries the controls, which is how the web page works:

| Body | Effect |
| --- | --- |
| `{"turn": 1}` | one detent clockwise; negative goes back |
| `{"press": 1}` | click the knob |
| `{"presshold": 1}` | hold it — opens the menu |
| `{"tap": 0}` | tap a pad: `0` left, `1` middle, `2` right |
| `{"swipe": 1}` | swipe across; negative goes the other way |
| `{"brightness": 40}` | `0`–`255` |

A pad tap and a finger arrive at the recogniser as the same thing, so anything
you can do standing at the desk you can do from the sofa.

## Check on it

`GET /api/state` needs no token:

```json
{"screen":"status","status":"FREE","brightness":48,"timer_left":1500,
 "timer_running":false,"fps":100.0,"ip":"192.168.68.105","clock":"18:48"}
```

`GET /api/clients` lists who is paired — names and dates, never tokens.

## When it stops working

**Everything returns 401.** The token was revoked, most likely by
**HOST → DROP** or a factory reset. Pair again.

**Nothing connects at all.** Check **WIFI → IP** on the panel. A DHCP lease
moves, and a Shortcut holding an old address will simply time out. Give the
panel a reservation on your router if you get tired of this.

**It works at home and not at the office.** Client isolation. Nothing in this
document can fix that; it is what the Mac helper's Bluetooth path is for.

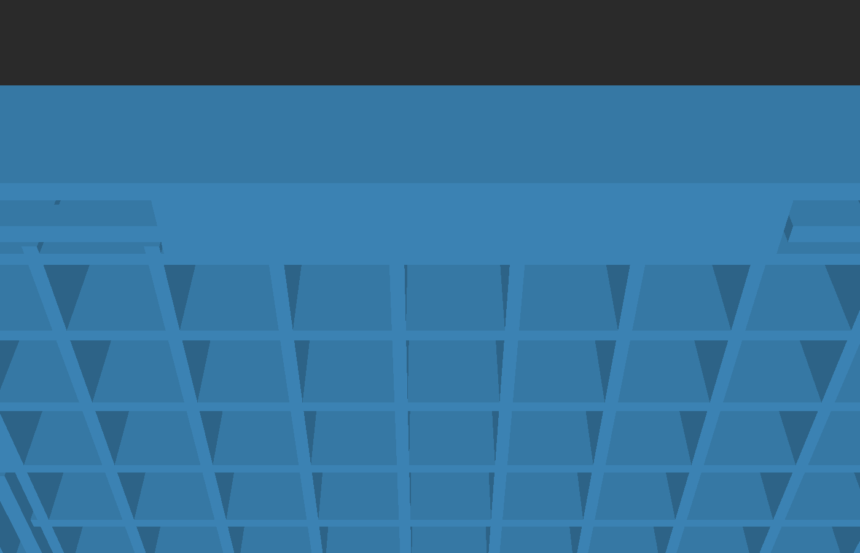
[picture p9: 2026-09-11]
hardware/img/grid-beams.png

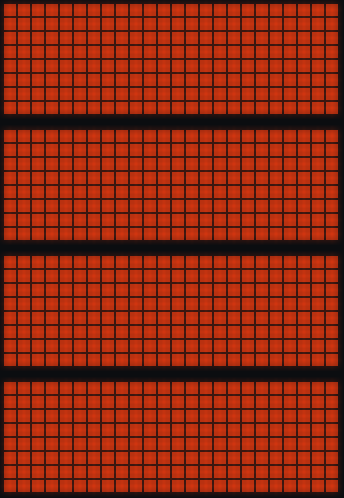
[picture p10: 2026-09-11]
docs/preview/solid.png

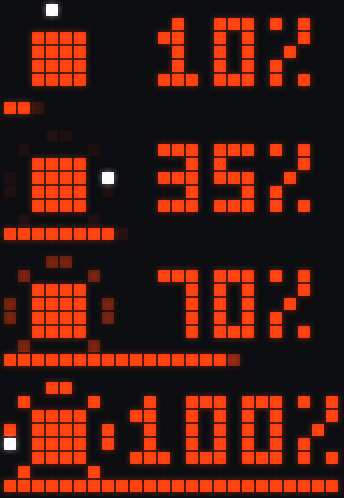
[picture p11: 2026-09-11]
docs/screens/brightness.png

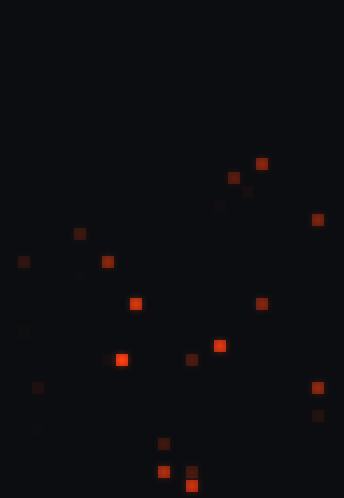
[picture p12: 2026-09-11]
docs/preview/sparkle.png

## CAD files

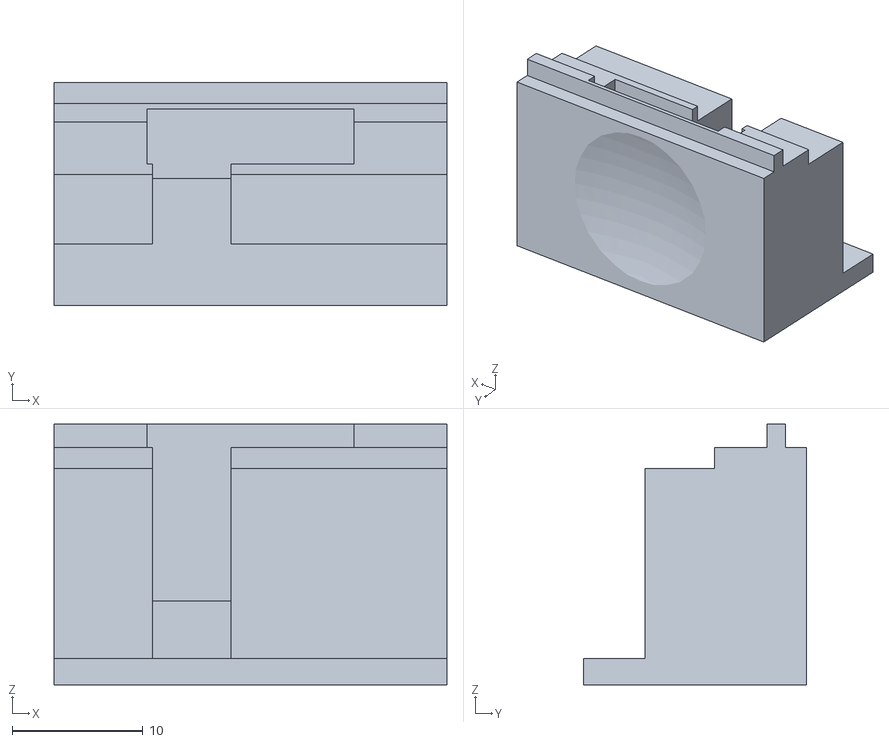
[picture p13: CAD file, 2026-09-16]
hardware/stl/t_touch.stl
30.0 x 17.0 x 19.9

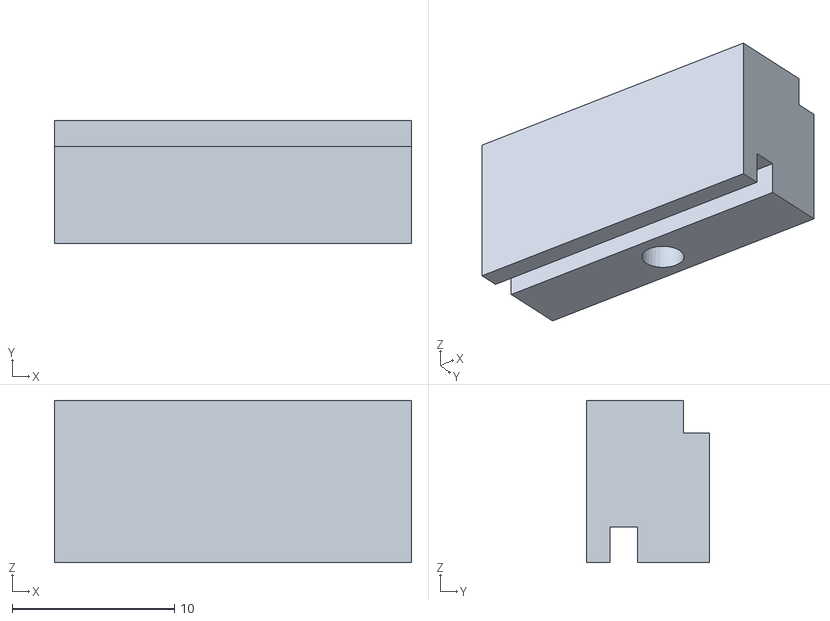
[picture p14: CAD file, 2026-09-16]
hardware/stl/g_seam.stl
22.0 x 7.60 x 10.0

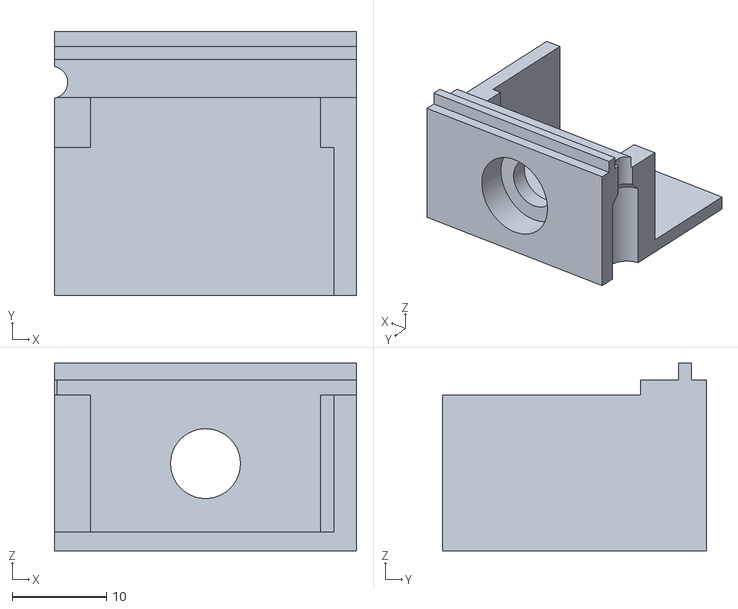
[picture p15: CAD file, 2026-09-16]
hardware/stl/t_knob.stl
32.0 x 28.0 x 19.9

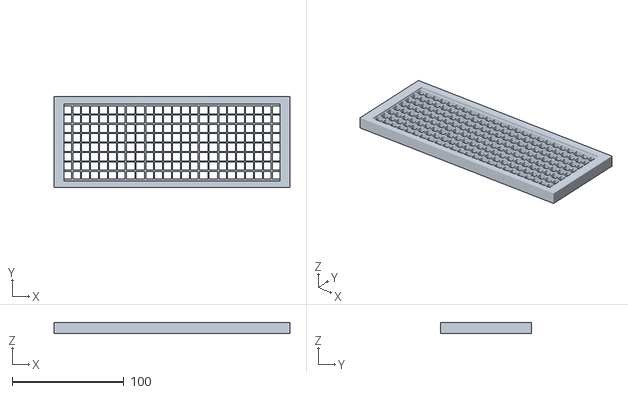
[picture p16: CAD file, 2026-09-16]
hardware/stl/grid.stl
211.4 x 81.6 x 10.0

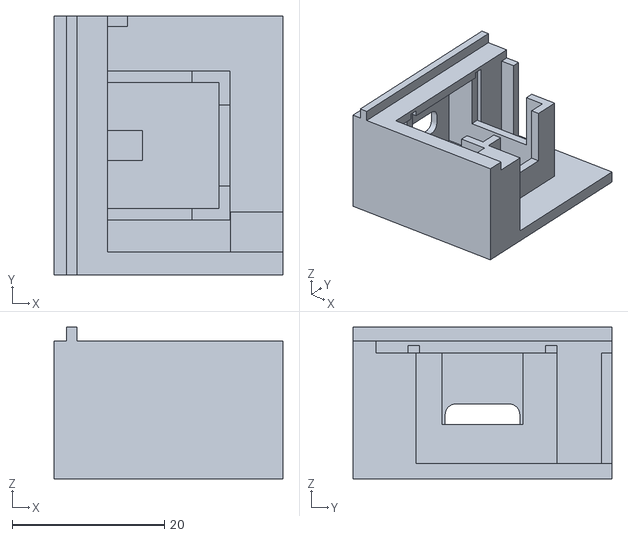
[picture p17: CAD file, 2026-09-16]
hardware/stl/t_port.stl
30.0 x 34.0 x 19.9

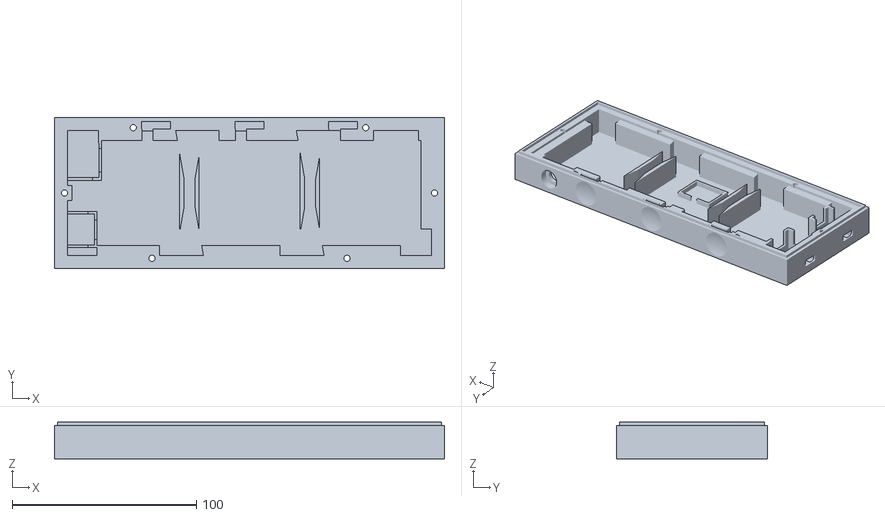
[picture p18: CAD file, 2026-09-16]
hardware/stl/tray.stl
211.4 x 81.6 x 19.9

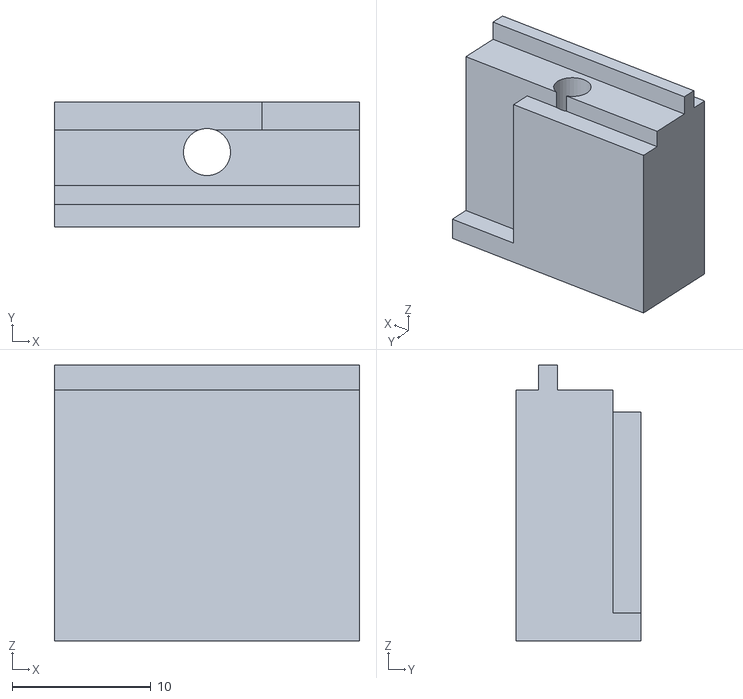
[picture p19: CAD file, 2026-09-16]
hardware/stl/t_seam.stl
22.0 x 9.00 x 19.9

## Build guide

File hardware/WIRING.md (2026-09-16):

# Wiring

Everything the ESP32-C3 SuperMini connects to, and why each pin was chosen.
The authoritative copy of the GPIO numbers is
[`firmware/main/pins.h`](../firmware/main/pins.h) — this file explains them.

> The panel is built and its mapping is confirmed. The encoder is soldered
> directly, and so are the three touch pads. The accelerometer is fitted too,
> on I²C.
>
> The web page still drives the pads, and always will: a web button and a
> soldered pad arrive at the recogniser as the same pin levels, so the remote
> control is not a stand-in for hardware that is now present but the same
> input by another route.

## GPIO map

| Function | GPIO | Notes |
| --- | --- | --- |
| LED data | 10 | to board 1 `DIN`, through a 330 Ω series resistor |
| Touch, left | 3 | TTP223 `OUT`, active high, momentary |
| Touch, middle | 4 | |
| Touch, right | 5 | |
| I²C `SDA` | 6 | MPU-6050 / MPU-6500 |
| I²C `SCL` | 7 | |
| MPU `INT` | 1 | optional, not used; the sensor is polled at frame rate |
| Encoder `A` | 20 | 10 kΩ pull-up to 3V3 |
| Encoder `B` | 21 | 10 kΩ pull-up to 3V3 |
| Encoder switch | 0 | to ground; 10 kΩ pull-up to 3V3 |

## Why these pins

**GPIO2, 8 and 9 are strapping pins** on the ESP32-C3 and are deliberately left
unused. Pulling one at boot changes the boot mode or the log output.

**GPIO20 and 21 are UART0.** They are free here only because the SuperMini has
no USB-serial bridge — the console and the flashing port are the C3's own USB
Serial/JTAG. `CONFIG_ESP_CONSOLE_USB_SERIAL_JTAG=y` in `sdkconfig.defaults` is
what keeps them free. Turn that off and the encoder will fight the log output.

**GPIO0 is not a strapping pin on the C3** (unlike the original ESP32), so it is
safe for the encoder switch.

**The C3 has no touch-sensor peripheral** — `SOC_TOUCH_SENSOR_SUPPORTED` is not
defined for this target. That is why the three touch zones are external TTP223
modules reading as plain digital inputs rather than the ESP32's built-in
capacitive sensing.

Each module has two solder jumpers, and the firmware assumes both are in their
factory position: **momentary** (output high only while touched) and **active
high**. Bridging the first makes every touch latch until the next one, so a
tap-to-toggle becomes a pad that is never released; bridging the second makes
an untouched pad read as permanently held, which the recogniser sees as a
chord and answers by putting the panel to sleep. Neither failure looks like a
wiring fault from the outside, so check the jumpers before the wires.

The pins are configured with pull-downs. A TTP223 drives its output actively,
so that is not there to set the level in normal use — it is what makes a module
that has come loose read as untouched instead of floating and inventing input.

**The C3 also has no PCNT peripheral**, so there is no hardware quadrature
counter for the encoder. `SOC_PCNT_SUPPORTED` is defined for the S3 and absent
here. The encoder must be decoded in a GPIO interrupt: polling at the 10 ms
frame tick drops detents, because a brisk flick of 20 detents per second puts
an edge every 12.5 ms.

## The encoder module

A bare EC11 has five pins and no power: three on one side (A, common, B) and
two on the other for the switch. Most of what you can actually buy is a KY-040
style **breakout board** instead, which adds a small PCB and labels the pins
`GND` `+` `S1` `S2` `KEY` — or `GND` `+` `SW` `DT` `CLK`, same thing.

| Module pin | Goes to | |
| --- | --- | --- |
| `GND` | GND | |
| `S1` (or `CLK`) | **GPIO20** | quadrature A |
| `S2` (or `DT`) | **GPIO21** | quadrature B |
| `KEY` (or `SW`) | **GPIO0** | the push switch |
| `+` (or `5V`) | **3V3** | never 5 V — see below |

### Connect `+` to 3.3 V, and never to 5 V

**The ESP32-C3's GPIOs are 3.3 V and are not 5 V tolerant.** The module's `+`
pin feeds 10 kΩ pull-up resistors that sit on `S1`, `S2` and `KEY`, so wiring
it to 5 V drives 5 V straight into three GPIOs through those resistors. Use
the board's 3V3 pin.

An earlier version of this file said to leave `+` unconnected, on the
reasoning that the ESP32-C3's internal pull-ups make the module's own
redundant. That was wrong, and wrong in a way that took a while to see.

With `+` floating, those three resistors do not disappear — they tie `S1`,
`S2` and `KEY` together through an undriven node. The internal pull-ups are
about 45 kΩ against the module's 10 kΩ, so the lines end up weakly held and
coupled to each other rather than cleanly high. Two things follow, and both
were observed on the bench:

- **Phantom input while nothing is being touched.** Twelve seconds of sitting
  perfectly still produced 32 illegal quadrature transitions, a detent that
  nobody turned, and a switch press that started the timer. The panel appeared
  to navigate and change status by itself.
- **The switch dipping whenever the knob turns.** Diagnosed at first as the
  push switch sharing a ground with the rotary contacts. It is really this
  coupling: working the rotary contacts disturbs the shared floating node, and
  `KEY` moves with it. The firmware carries two guards against this — it will
  not read the switch while the knob is moving, and it rejects any contact
  shorter than a finger can make — but they are mitigations for a wiring
  fault, not a substitute for fixing it.

Powering `+` from 3V3 puts strong 10 kΩ pull-ups on all three lines and makes
the coupling node a supply rail instead of an antenna.

## The bare EC11, and the three resistors it needs

This is the final build: the encoder desoldered from its breakout board, or
bought bare. A bare EC11 is the switch and the two contacts and nothing else —
five pins, no power pin, and **no resistors**. There is no `+` to connect and
nothing is lost by its absence: the shared node that caused the fault above is
removed along with the board it lived on.

> **`C` goes to GND, and to nothing else.** This is the one thing to get right,
> and the section above is why it is easy to get wrong: on a KY-040 you connect
> `+` to **3V3**, and that habit does not carry over. A bare EC11 has no `+`.
> Its contacts work by pulling a line **down**, so the common must sit at
> ground. Wire `C` to 3V3 and every contact connects its line to the voltage
> the pull-ups are already holding it at: nothing moves, the levels read high
> forever, and all three lines look dead at once while board ground tests
> perfectly fine. The three resistors go to 3V3; the common does not.

| EC11 pin | Goes to | |
| --- | --- | --- |
| `A` | **GPIO20** | quadrature A, **and** 10 kΩ to 3V3 |
| `C` (common, centre of the three) | **GND** | never 3V3 — see above |
| `B` | **GPIO21** | quadrature B, **and** 10 kΩ to 3V3 |
| switch pin 1 | **GPIO0** | **and** 10 kΩ to 3V3 |
| switch pin 2 | **GND** | never 3V3, for the same reason |

### Finding the pins on the part

Do not trust a picture; two minutes with a multimeter on continuity settles it
and costs less than desoldering.

- The **two pins on their own side** are the push switch. They short to each
  other while the shaft is pressed and are open otherwise. No polarity.
- The **three pins on the other side** are `A`, `C`, `B`, with `C` in the
  centre. Turning the shaft slowly makes and breaks `A`–`C` and `B`–`C` in
  turn; `A`–`B` never closes on its own. If the middle pin is the one that
  shows continuity to *both* outer pins as you turn, that is `C`.
- Some EC11s also have **mounting lugs** on the body. They are mechanical and
  connect to nothing.

### Fit the three 10 kΩ pull-ups

One from each of `A`, `B` and the switch pin to **3V3**. Not optional, and not
the same thing as the module's resistors — those are gone with the module.

The firmware enables the ESP32-C3's internal pull-ups, and on a bench with
short wires those alone will appear to work. They are around 45 kΩ, which is
weak enough that the line sits at a high impedance between contact closures,
and a high-impedance line a few centimetres from 192 WS2812s switching at
100 Hz is an antenna. The wires are also longer in the assembled case than on
the bench, which makes it worse exactly where it is hardest to get at.

This is a different mechanism from the coupling fault above — pickup on a weak
pull-up, rather than three lines tied through an undriven node — and it shares
the same symptom, which is input nobody made. 10 kΩ lowers the impedance by
more than four times and settles it. Three resistors, fitted before the case
closes, against a fault that otherwise surfaces only after it has.

The switch pull-up matters as much as the two quadrature ones. The firmware
carries guards against a disturbed switch line — it will not read the switch
while the knob is moving, and it rejects any contact shorter than a finger can
make — and those guards cost responsiveness. They exist to survive bad
signals, not to excuse them.

### If the direction comes out backwards

Swap the two quadrature lines — `S1` and `S2` on the module, `A` and `B` on a
bare EC11. Which line is which only sets the sense of rotation, and getting it
the wrong way round is the expected outcome of a coin flip rather than a
mistake.

### The module will not fit the case

The enclosure pocket is sized for a bare EC11 lying behind the top wall, not
for a breakout PCB. Either desolder the encoder from the module and wire it
directly — the four connections above are the same — or switch the model to its
`KY040_BACK` layout, which puts the module flat under board 3 with the shaft
through the back. For bench work on jumper wires, none of this matters.

## Power

```
USB-C breakout  5V ──┬── 1000 µF ──┬── panel 5V (all three boards)
                     │             └── ESP32-C3 5V pin
                     └── 1N5819 ──> (blocks back-feed into the ESP32's
                                     own USB port when both are plugged in)
GND ─────────────────┴── common to everything
```

- **330 Ω** in series with the LED data line, close to the ESP32, to damp
  reflections on the first edge.
- **1000 µF** across the supply at the panel end, to absorb the inrush when a
  frame turns a lot of LEDs on at once.
- **1N5819** so that plugging the ESP32's own USB port in while the barrel
  supply is connected does not back-feed 5 V into the host.
- Feed 5 V to **each of the three boards** rather than daisy-chaining power
  through the board-to-board links. At 2.5 A the copper in those links is the
  weak point, and the far board browns out first.

### Wire gauge, which is not a detail

| Run | Gauge | Why |
| --- | --- | --- |
| 5 V to each board | **20–22 AWG** | carries the current |
| GND, every run | **20–22 AWG** | carries the same current *back* |
| LED data | 26–28 AWG is fine | microamps — but see below |
| Encoder, touch, I²C | 26–30 AWG is fine | signals only |

28 AWG is 0.081 mm² and about 213 mΩ per metre, against 53 for 22 AWG and 33
for 20. Its chassis-wiring ampacity is roughly 1.4 A, so at the 2.5 A design
target it is already past rating before any argument about voltage drop.

**But the drop is not the failure mode that bites first, and this is the part
worth understanding.** A mostly-dark frame draws a couple of hundred
milliamps, where even 28 AWG drops single-digit millivolts — so a panel can
glitch on a dark screen while the arithmetic says the wiring is fine.

The mechanism is the **ground**. A WS2812B decides whether an incoming bit is
high or low relative to *its own* ground pin. Chain the boards' grounds through
thin wire and each board sits at a slightly different, constantly moving
potential from the one before it, because the LEDs' own drivers switch their
current on and off thousands of times a second and that current comes back
along exactly this wire. Board 2 sends a clean edge referenced to *its* ground;
board 3 measures it against *its* ground; the difference is error, and it is
largest at the end of the chain because that is where the offsets have
accumulated.

Which is why this shows up as **the last board flickering — including LEDs the
frame says are off — while the first two are perfect**. It is not a brightness
problem and it is not a distance problem. Thick wire hides it; thin wire does
not.

So: ground is not the wire you economise on. It carries every milliamp the 5 V
wire does, and it doubles as the reference for the only signal in the system
that matters.

## Panel chain

Three 65 mm 8×8 WS2812B boards, chained left to right as you face the panel:

```
ESP32 GPIO10 ──330Ω──> [board 1] DOUT ──> [board 2] DOUT ──> [board 3]
```

How the LEDs are wired *inside* one board varies between suppliers, which is
why `kWiring` in `firmware/components/panel/include/panel/config.h` is a config
value and not an assumption. It is settled for this panel; see "The LED mapping" in the README.

## Physical placement

From the parametric model in
[`enclosure/ws2812b_8x24_enclosure.py`](enclosure/ws2812b_8x24_enclosure.py).
The case is 205.6 mm long and stands upright on its front edge.

| Part | Position | Notes |
| --- | --- | --- |
| Touch zones | x = 55.0, 102.8, 150.6 mm on the top edge | upright in pockets, pad facing a 1.5 mm skin, each under a 6 mm dimple |
| Encoder | x = 176.0 mm on the top edge | bare EC11 lying behind the top wall, shaft out through it |
| MPU-6050 | (102.8, 30.0) mm | flat on the compartment floor under board 2, inside a fence |

The accelerometer's axis convention is **not yet established**. The case stands
on its front edge, so gravity rests along an in-plane axis in normal use and
along the board normal when the case is laid flat. Which signed axis is which
has to be measured on the real board before "lay it flat to sleep" can work.

## Joining wires

Several grounds and several 5 V feeds meet at the same points. Solder them
together and cover the joint with heat-shrink rather than using a terminal
block — there is no room in the compartment for one, and the model's wire
channels are sized for bare wire.

## The accelerometer is probably not an MPU-6050

The board fitted here answers `WHO_AM_I` with **0x70**, which is an **MPU-6500**.
A great many modules sold as "GY-521 / MPU-6050" carry 6500 silicon, and the
label on the listing is not evidence either way. The driver accepts 0x68
(6050), 0x70 (6500) and 0x71 (9250), names the one it found in the log, and
refuses to configure anything it does not recognise.

They are register-compatible for everything used here — wake, sample rate,
range, and the six accelerometer bytes at `0x3B` — with **one** exception that
matters. On the 6050, the `CONFIG` (0x1A) low-pass filter serves the gyro *and*
the accelerometer. On the 6500 and 9250 it serves only the gyro, and the
accelerometer has its own filter in `ACCEL_CONFIG2` (0x1D). A driver written
for the 6050 and run on a 6500 therefore reads acceleration **unfiltered at
1 kHz** — which, on a panel bolted to a desk that someone types on, is a steady
supply of knocks that never happened. `0x1D` is written only when the part that
has it identifies itself.

Range is **±4 g**, not the ±2 g default. `tap_g` and `shake_g` are *jolts* —
changes in the magnitude of the vector, 1.2 g and 1.8 g — and the panel rests
at 1 g before the knock lands, so a shake worth recognising takes the
instantaneous magnitude near 3 g. At ±2 g that clips, and a clipped peak reads
as a *smaller* jolt than it was: the harder you hit it, the less it notices.

### Checking it

The status line carries `g=` and `plane=`. At rest `g` is gravity, so anything
that is not about 1.00 means the scaling or the wiring is wrong — this board
reads 0.97, which is ordinary factory offset on an uncalibrated part. `plane`
is `sqrt(ax² + ay²)`, the component the flat-versus-upright test is made on:
standing up it is ~1.00 and laid flat it is ~0. If those are the wrong way
round the panel will decide it is lying down while standing upright, and then
sleep a second later for no visible reason.

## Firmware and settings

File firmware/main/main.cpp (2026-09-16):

// Pixelbar: 8x24 WS2812B desk panel on an ESP32-C3 SuperMini.
//
// The loop is three lines of work and a lot of care about when they happen:
// read the inputs and advance the model, draw it, clock it out. Everything
// interesting lives above this file, in two components that know nothing about
// ESP-IDF and are tested on a laptop.
#include <cstdio>
#include <cstring>

#include "driver/gpio.h"
#include "driver/temperature_sensor.h"
#include "esp_log.h"
#include "esp_timer.h"
#include "freertos/FreeRTOS.h"
#include "freertos/task.h"
#include "panel/anim.h"
#include "panel/config.h"
#include "panel/framebuffer.h"
#include "board/board.h"
#include "net/net.h"
#include "panel/patterns.h"
#include "panel/renderer.h"
#include "panel/screens.h"
#include "panel/transition.h"
#include "pins.h"
#include "ui/app.h"
#include "ws2812.h"

namespace {

const char* TAG = "pixelbar";

// Hold the mapping test at boot, long enough to watch the head sweep the whole
// panel twice. Zero because kWiring is confirmed: it was taken from a WLED
// setup running on this panel, which is the only evidence that settles it.
// Pattern::MapTest is still there for whenever the wiring is in doubt again.
constexpr int64_t kMapTestSeconds = 0;

// How long the render loop must survive before an over-the-air update is
// confirmed and the previous image released. See the call site.
constexpr int64_t kHealthySeconds = 10;

panel::micros_t now_us() {
  return static_cast<panel::micros_t>(esp_timer_get_time());
}

}  // namespace

extern "C" void app_main(void) {
  ESP_LOGI(TAG, "pixelbar: %d x %d, %d LEDs, %d fps", panel::kWidth, panel::kHeight,
           panel::kNumLeds, panel::kFramesPerSecond);

  ws2812_handle_t strip = nullptr;
  ESP_ERROR_CHECK(ws2812_new(pins::kLedData, panel::kNumLeds, &strip));
  ESP_ERROR_CHECK(ws2812_clear(strip));

  static panel::Framebuffer fb;
  static panel::Engine engine;
  static panel::ScreenManager screens;
  static panel::Renderer renderer;
  // Seeds the per-channel dither offsets. Without this every channel starts
  // level and they all cross the threshold on the same frame, which is a whole
  // panel shimmering in step — far more visible than the stepping the dither
  // exists to remove.
  renderer.reset_dither();
  static panel::FrameClock clock;
  static panel::FpsMeter meter;
  // Double buffered: the RMT peripheral reads one while the next is drawn.
  static uint8_t wire[2][panel::kNumLeds * 3];
  int cur = 0;

  engine.set_pattern(panel::Pattern::MapTest);
  if (kMapTestSeconds > 0) {
    ESP_LOGI(TAG, "mapping test for %llds: the white pixel should sweep left to "
                  "right along the top row, starting at the red marker",
             static_cast<long long>(kMapTestSeconds));
  }

  // Pins, pull-ups, the encoder interrupt and NVS. Without this the inputs are
  // unconfigured: every pin floats, three of them wander in lockstep picking up
  // the same ambient noise, and the encoder interrupt does not exist — which
  // reads exactly like an encoder that is wired wrong.
  const esp_err_t hw = board::init();
  if (hw != ESP_OK) ESP_LOGE(TAG, "board init failed: %s", esp_err_to_name(hw));

  static board::DevicePorts ports;
  static ui::App app;
  app.begin(ports, 0.0);
  ESP_LOGI(TAG, "ready: turn the knob to change view, hold it for the menu");

  // WiFi and the web page. Started, not waited for: a device whose panel does
  // not light until a router answers is a worse device.
  const esp_err_t nerr = net_start();
  if (nerr != ESP_OK) ESP_LOGW(TAG, "network not available: %s", esp_err_to_name(nerr));

  // Which pins actually move when you turn the knob. Resting levels cannot
  // tell a floating pin from a correctly pulled-up one; edges can.
  constexpr bool kPinScan = false;
  if (kPinScan) {
    board::scan_begin();
    // What the silicon thinks these pins are, rather than what the code asked
    // for. This is the line that cleared the firmware of the dead encoder: it
    // showed GPIO20 and 21 as plain GPIO inputs, pulled up, any-edge interrupt
    // armed — leaving nowhere for the fault to be except the wiring, which is
    // where it was.
    ESP_LOGW(TAG, "pin configuration for the encoder (0, 20, 21) and a pad (3):");
    gpio_dump_io_configuration(
        stdout, (1ULL << 0) | (1ULL << 3) | (1ULL << 20) | (1ULL << 21));
  }

  // The chip's own temperature, because "it goes wrong after half an hour" is
  // a thermal statement and nothing here could measure one. It costs a
  // peripheral nobody else is using and one reading every couple of seconds.
  temperature_sensor_handle_t tsens = nullptr;
  {
    temperature_sensor_config_t tcfg = TEMPERATURE_SENSOR_CONFIG_DEFAULT(-10, 80);
    if (temperature_sensor_install(&tcfg, &tsens) != ESP_OK ||
        temperature_sensor_enable(tsens) != ESP_OK) {
      tsens = nullptr;
      ESP_LOGW(TAG, "no internal temperature sensor");
    }
  }
  unsigned long frame_drops = 0;

  const int64_t boot_us = esp_timer_get_time();
  bool mapping = kMapTestSeconds > 0;
  bool warned_about_power = false;
  ui::EventType last_ev = ui::EventType::None;
  int64_t last_log_us = boot_us;

  const TickType_t period = pdMS_TO_TICKS(1000 / panel::kFramesPerSecond);
  TickType_t last_wake = xTaskGetTickCount();

  while (true) {
    const panel::micros_t t_us = now_us();
    const int64_t uptime_s = (esp_timer_get_time() - boot_us) / 1000000;
    const panel::Anim a = clock.tick(t_us);

    if (mapping && uptime_s >= kMapTestSeconds) {
      mapping = false;
      ESP_LOGI(TAG, "mapping test done");
    }

    // Tell the bootloader this image is worth keeping — but only after the
    // render loop has actually run for a while.
    //
    // With rollback enabled a freshly flashed slot boots as *pending*, and any
    // reset before this call puts the previous image back. Ten seconds of real
    // frames is a weak proof of health and a sufficient one: it covers the
    // failures that make a device unreachable, which are a crash or a panic
    // loop in the first moments, and those are exactly the ones you cannot fix
    // over the network. Confirming at startup instead would leave the flag set
    // and the old image discarded before anything had been demonstrated.
    static bool confirmed = false;
    if (!confirmed && uptime_s >= kHealthySeconds) {
      confirmed = true;
      net_mark_healthy();
    }

    if (mapping) {
      // Wiring check: a crisp single pixel, so dithering is off for it.
      engine.render_us(fb, t_us);
    } else {
      if (kPinScan) board::scan_poll();

      // Drain whatever the web page asked for, once, at the top of the frame.
      //
      // Handlers run on the server's task and never touch the model: they put a
      // command on a queue and this is the only place it is read. Reaching into
      // the App from a handler would mutate state halfway through a frame that
      // is already being drawn from it, and the failure would be a rare torn
      // frame rather than anything a test would catch.
      net_cmd_t cmd;
      while (net_take_cmd(&cmd)) {
        switch (cmd.kind) {
          // Pads and knob arrive as levels and detents, so the recogniser sees
          // exactly what the hardware would produce.
          case NET_CMD_TAP: ports.pads().tap(cmd.a); break;
          case NET_CMD_HOLD: ports.pads().set_held(cmd.a, true); break;
          case NET_CMD_RELEASE: ports.pads().set_held(cmd.a, false); break;
          case NET_CMD_SWIPE: ports.pads().swipe(cmd.a); break;
          case NET_CMD_TURN: ports.nudge_encoder(cmd.a); break;
          case NET_CMD_PRESS: ports.press_switch(0.06f); break;
          case NET_CMD_PRESS_HOLD: ports.press_switch(0.60f); break;
          // These two are values rather than gestures, so they go straight in.
          case NET_CMD_STATUS: app.set_status_external(cmd.a); break;
          case NET_CMD_BRIGHTNESS: app.set_brightness_external(cmd.a); break;
          default: break;
        }
      }

      // The radio's state reaches the model through the ports, never directly:
      // `board` knows nothing about WiFi and `ui` knows nothing about either.
      ports.set_wifi(net_connected());
      ports.set_time_valid(net_time_valid());
      {
        // The two enums are deliberately separate — `ui` may not include an
        // IDF header — so this is the one place they are mapped, and it is
        // three lines rather than a shared header that would couple them.
        const net_mode_t m = net_mode();
        ports.set_ota(net_ota_progress());
        ports.set_passkey(net_passkey());
        ports.set_net(m == NET_MODE_ONLINE  ? ui::Ports::NetMode::Online
                      : m == NET_MODE_JOINING ? ui::Ports::NetMode::Joining
                      : m == NET_MODE_OFF     ? ui::Ports::NetMode::Off
                                              : ui::Ports::NetMode::Setup,
                      net_panel_text());
      }

      ports.advance(a.dt);
      app.update(a.dt, a.t);
      app.render(fb, a);

      // A live trace of what the recogniser made of the inputs. A press lasts
      // sixty milliseconds and a periodic log samples every fifteen hundred, so
      // without this the one thing you want to see is the one thing you never
      // catch. Logged on change rather than every frame.
      const ui::EventType ev = app.last_event();
      if (ev != last_ev) {
        last_ev = ev;
        if (ev != ui::EventType::None) {
          ESP_LOGI(TAG, "  %-14s -> %s / %s", ui::event_name(ev),
                   panel::screen_name(app.screen()),
                   panel::status_label(app.state().status));
        }
      }
    }

    const panel::RenderStats st =
        renderer.render(fb, wire[cur], app.state().brightness, app.max_ma(),
                        panel::kWiring);
    if (st.power_scale < 1.0f && !warned_about_power) {
      warned_about_power = true;
      ESP_LOGW(TAG, "power cap active: scaling to %.0f%% to stay under %.0f mA",
               st.power_scale * 100.0f, app.max_ma());
    }

    // Wait for the previous frame only now, after all the drawing: its time on
    // the wire has overlapped with this frame's work.
    const esp_err_t err = ws2812_wait(strip, 50);
    if (err != ESP_OK) ESP_LOGE(TAG, "led wait failed: %s", esp_err_to_name(err));
    // The return was dropped on the floor. A frame that fails to queue — or
    // whose predecessor did not finish inside the wait — is simply not shown,
    // and the panel keeps the one before it; from across the room that is a
    // flicker, and there was nothing anywhere saying it had happened. Counted
    // rather than logged per occurrence, because if it starts happening it
    // will happen at a hundred hertz.
    if (ws2812_write_async(strip, wire[cur]) != ESP_OK) ++frame_drops;
    cur ^= 1;

    meter.tick(t_us);
    if (esp_timer_get_time() - last_log_us > 1500000) {
      last_log_us = esp_timer_get_time();
      // Both are here for the same reason: a fault that takes half an hour to
      // appear needs something that was being watched the whole time.
      float chip_c = -1.0f;
      if (tsens) temperature_sensor_get_celsius(tsens, &chip_c);
      const unsigned free_heap =
          static_cast<unsigned>(esp_get_free_heap_size());
      // The encoder's illegal-transition count is here on purpose: a non-zero
      // value at ordinary turning speed means the interrupt is being starved,
      // and that is far easier to see in a log line than on the panel.
      ESP_LOGI(TAG,
               "fps=%.1f avg=%.2fms max=%.2fms power=%.0f%% screen=%s "
               "detents=%ld illegal=%lu  pads=%c%c%c enc A=%d B=%d sw=%d %s "
               "g=%.2f plane=%.2f %.1fC heap=%u drops=%lu bright=%d(%d%%)",
               meter.fps(), meter.frame_ms_avg(), meter.frame_ms_max(),
               st.power_scale * 100.0f, panel::screen_name(app.screen()),
               static_cast<long>(ports.encoder_detents()),
               static_cast<unsigned long>(ports.encoder_illegal()),
               (ports.raw_pads() & 1) ? 'L' : '-',
               (ports.raw_pads() & 2) ? 'M' : '-',
               (ports.raw_pads() & 4) ? 'R' : '-',
               (ports.raw_encoder() & 1) ? 1 : 0,
               (ports.raw_encoder() & 2) ? 1 : 0,
               (ports.raw_encoder() & 4) ? 1 : 0,
               panel::status_label(app.state().status), ports.last_g(), ports.last_plane(), chip_c, free_heap, frame_drops,
               app.state().brightness,
               (app.state().brightness * 100 + 127) / 255);
      if (kPinScan) {
        char scan[192];
        board::scan_report(scan, sizeof(scan));
        ESP_LOGI(TAG, "pins gpio:level/edges  %s", scan);
      }
      meter.reset_peak();
    }

    // What the web page shows. Written once a frame and read by the server's
    // task; a torn read would at worst mix two frames of a status display.
    {
      net_status_t ns = {};
      snprintf(ns.screen, sizeof(ns.screen), "%s", panel::screen_name(app.screen()));
      snprintf(ns.status, sizeof(ns.status), "%s",
               panel::status_label(app.state().status));
      ns.brightness = app.state().brightness;
      ns.timer_left_s = app.state().timer_left_s;
      ns.timer_running = app.state().timer_running;
      ns.fps = meter.fps();
      ns.detents = ports.encoder_detents();
      ns.illegal = ports.encoder_illegal();
      ns.menu_index = static_cast<int16_t>(app.state().menu_index);
      snprintf(ns.set_label, sizeof(ns.set_label), "%s",
               app.state().set_label ? app.state().set_label : "");
      snprintf(ns.set_text, sizeof(ns.set_text), "%s",
               app.state().set_text ? app.state().set_text : "");
      net_publish(&ns);
      // What the panel means, for anyone watching it from elsewhere. Rate
      // limited inside; see net_publish_frame.
      net_publish_frame(reinterpret_cast<const uint8_t*>(fb.pixels()),
                        panel::kNumLeds);
    }

    vTaskDelayUntil(&last_wake, period);
  }
}

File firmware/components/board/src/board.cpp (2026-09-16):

#include "board/board.h"

#include <cstdio>
#include <cmath>
#include <cstring>
#include <ctime>

#include "driver/gpio.h"
#include "driver/i2c_master.h"
#include "hal/gpio_ll.h"
#include "esp_attr.h"
#include "esp_check.h"
#include "esp_err.h"
#include "esp_log.h"
#include "esp_timer.h"
#include "nvs.h"
#include "nvs_flash.h"
#include "net/net.h"
#include "pins.h"

namespace board {
namespace {

const char* TAG = "hal";

// ------------------------------------------------------------- encoder
//
// Decoded in an interrupt rather than polled, because the ESP32-C3 has no PCNT
// peripheral — SOC_PCNT_SUPPORTED is defined for the S3 and absent here. At the
// 10 ms frame tick a brisk flick of 20 detents a second puts an edge every
// 12.5 ms, so polling would drop detents exactly when the knob is being spun
// hardest. The interrupt accumulates and the frame drains it, so a late frame
// loses nothing.

ui::Quadrature g_quad;
volatile int32_t g_detents = 0;
volatile uint32_t g_illegal = 0;

// In IRAM, along with everything it touches — and that second clause has to be
// true rather than merely intended.
//
// An interrupt living in flash stalls for the milliseconds the cache is
// disabled during an NVS commit, and on an encoder that is detents silently
// going missing. Worse than missing detents, though, is what happens during a
// firmware update: the cache is off for far longer, and a flash access from an
// interrupt there is not a stall but a Cache error panic. That is exactly how
// the first over-the-air update died — the ISR was correctly marked IRAM_ATTR
// and correctly registered with ESP_INTR_FLAG_IRAM, and then called
// gpio_get_level(), which lives in flash. The comment above this function
// already claimed otherwise and was wrong.
//
// gpio_ll_get_level is a static inline that compiles down to one register
// read, so it lands inside this function rather than being a call out to
// somewhere the cache may not be able to reach. Quadrature::update is
// header-inline for the same reason.
void IRAM_ATTR encoder_isr(void* /*arg*/) {
  const bool a = gpio_ll_get_level(&GPIO, pins::kEncoderA) != 0;
  const bool b = gpio_ll_get_level(&GPIO, pins::kEncoderB) != 0;
  g_quad.update(a, b);
  g_detents = g_quad.detents();
  g_illegal = g_quad.illegal();
}

esp_err_t init_encoder() {
  gpio_config_t in = {};
  in.pin_bit_mask = (1ULL << pins::kEncoderA) | (1ULL << pins::kEncoderB);
  in.mode = GPIO_MODE_INPUT;
  in.pull_up_en = GPIO_PULLUP_ENABLE;  // EC11 contacts pull to ground
  in.intr_type = GPIO_INTR_ANYEDGE;
  ESP_RETURN_ON_ERROR(gpio_config(&in), TAG, "encoder pins");

  gpio_config_t sw = {};
  sw.pin_bit_mask = 1ULL << pins::kEncoderSw;
  sw.mode = GPIO_MODE_INPUT;
  sw.pull_up_en = GPIO_PULLUP_ENABLE;
  sw.intr_type = GPIO_INTR_DISABLE;  // the switch is read at frame rate
  ESP_RETURN_ON_ERROR(gpio_config(&sw), TAG, "encoder switch");

  // Prime the decoder on the resting position, so the first movement is
  // measured from where the knob actually is rather than from zero.
  g_quad.update(gpio_get_level(pins::kEncoderA) != 0,
                gpio_get_level(pins::kEncoderB) != 0);

  esp_err_t err = gpio_install_isr_service(ESP_INTR_FLAG_IRAM);
  if (err == ESP_ERR_INVALID_STATE) err = ESP_OK;  // already installed
  ESP_RETURN_ON_ERROR(err, TAG, "isr service");
  ESP_RETURN_ON_ERROR(gpio_isr_handler_add(pins::kEncoderA, encoder_isr, nullptr),
                      TAG, "isr A");
  ESP_RETURN_ON_ERROR(gpio_isr_handler_add(pins::kEncoderB, encoder_isr, nullptr),
                      TAG, "isr B");
  return ESP_OK;
}

// ------------------------------------------------------------- touch pads
//
// Configured as inputs whether or not the modules are fitted. A TTP223 drives
// its output actively, so a pull-down is what keeps an unpopulated pad reading
// low instead of floating and inventing touches.
esp_err_t init_touch() {
  gpio_config_t t = {};
  t.pin_bit_mask = (1ULL << pins::kTouchLeft) | (1ULL << pins::kTouchMiddle) |
                   (1ULL << pins::kTouchRight);
  t.mode = GPIO_MODE_INPUT;
  t.pull_down_en = GPIO_PULLDOWN_ENABLE;
  t.intr_type = GPIO_INTR_DISABLE;
  return gpio_config(&t);
}
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

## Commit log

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2026-09-11 feat: UI screens, and stop scrolling text that already fits
    Adds the screens the touch zones and the encoder actually drive, and fixes
    text that was scrolling when it did not need to.
    A status word is 23 px wide in the proportional font and the panel is 24, so
    BUSY fits whole. Scrolling something that already fits makes it harder to read
    from across the room, which is the entire job of a status light. Text now
    centres when it fits and scrolls only when it must.
    Screens: status, clock, focus timer, brightness, colour picker, timer length,
    sleep and a WiFi splash. Each is a pure function of UiState and the clock, so
    the input layer and the state machine can be built and tested separately fro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
    [patterns.cpp]
2026-09-11 feat: icons, transitions and 100 fps animation
    Turns the panel from something that draws correctly into something that looks
    designed: an icon and a mini-font label instead of a scrolling word, semantic
    transitions between modes, and continuous motion on every screen.
    Most of the work was not adding animation. It was removing the six places the
    pipeline quantised motion, because without that more animation would only have
    looked more stepped:
    - the loop ran at 62.5 fps, not 60: pdMS_TO_TICKS(1000/60) truncates to 16
    ticks. Now 100 fps, which divides the 1 kHz tick exactly
    - dt was rounded to 1 ms, a tenth of a frame at 100 fps. Now microseconds
    - text scrolled a whole LED at a time. Now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
    [framebuffer.h]
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2026-09-11 fix: make the screens tell the truth
    Four couplings that were drawn but not wired, and the documentation that
    described a version of the code that no longer exists.
    The Brightness screen was a readout of a value that reached nothing: the render
    call passed the compile-time kDefaultBrightness, not ui.brightness. The colour
    picker moved a cursor over a hue it had no way to apply, so accent_from_hue
    gives it one. status_icon() had no Call case and fell through to the FREE ring,
    so a change into or out of CALL turned over the wrong picture — visible only
    since elements started turning over in place.
    The fourth is subtler. ScreenManager snapshotted the outgoing UiState lazily,
    on the first tr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
    [main.cpp]
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2026-09-11 feat: the state machine, and a simulator to drive it with
    ui::App owns the state, the screen stack and the recogniser, so the firmware
    and the simulator both reduce to the same three lines a frame. tools/sim.cpp
    runs all of it at 100 fps in a terminal, drawing the panel as truecolour
    half-blocks read back out of the GRB wire bytes — through the real LED mapping
    and the real gamma table, so a mapping mistake shows up there rather than on a
    soldered board.
    Keystrokes become raw pad levels and encoder counts, not events. A tap in the
    simulator is a pad going down and coming back up over six frames; a swipe is a
    scripted drag with the overlaps a finger actually makes. That means the
    recognise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
    [app.h]
2026-09-11 feat: a menu, a status picker, and badges for the words that never fit
    The 15 px label box beside an 8 px icon has always been the constraint that
    shaped the status screen, and AWAY, FOCUS, LUNCH and MEET do not fit it. Rather
    than scroll them, they drop the icon and take the whole panel as a knocked-out
    badge: a filled field in the status colour with the word cut out in black. It
    is the device I found in the Busy Bar frames and had not built. Colour carries
    the meaning, so no picture is needed, and the lit area is three times larger,
    which is most of why it reads from further away.
    The two layouts have to turn over into each other, because you can go straight
    from BUSY to FOCUS. Both now s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
    [app.h, sprite.cpp, sprite.h]
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2026-09-11 fix: the LED mapping was a guess, and the guess was wrong
    Confirmed against a WLED setup running on this panel, which is the only kind of
    evidence that settles it. WLED describes the same four things under different
    names, and three of the four matched:
    1st LED: Top / Left Corner::TopLeft agreed
    Orientation: Horizontal Axis::Row agreed
    Panel offsets 0, 8, 16 chainRightToLeft=false agreed
    Serpentine: unchecked serpentine = true WRONG
    The boards are progressive, not serpentine: every row runs left to right and
    the chain drops back to the left at the end of each one. The comment in
    config.h said "most 65 mm 8x8 boards are TopLeft / R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
    [app.h, main.cpp]
2026-09-11 feat: the encoder, on real pins, driving the real model
    components/board is the device side of ui::Ports: GPIO, NVS, and the virtual
    pads. main.cpp loses the scripted tour and runs ui::App instead, so what the
    panel shows is now decided by input rather than by an array.
    Named `board` and not `hal` because ESP-IDF already has a component called hal
    — the one that provides hal/gpio_types.h and hal/sha_types.h. A second
    component of that name shadows it, and the first thing you learn is that
    mbedtls cannot find its own headers.
    The encoder is decoded in a GPIO interrupt, in IRAM, along with everything it
    touches. An interrupt living in flash stalls for the milliseconds the cache is
    disabled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
    [board.cpp, gesture.cpp, gesture.h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]
2026-09-11 fix: the LED output stops racing a deadline, and the dither stops blinking
    Three problems seen on the first real panel, two of them mine and one of them
    the chip's.
    The travelling flicker was RMT underrun. SOC_RMT_SUPPORT_DMA is defined for the
    S3 and absent for the C3, so RMT here is refilled from an interrupt: 96 refills
    a frame, 9,600 a second, each with about 58 us of runway against a 50 us latch.
    Miss one and the strip latches a partial frame and restarts at LED 0, and
    because the miss lands somewhere different each time, the disturbance walks
    along the panel. It was worse while the encoder was turning, which is exactly
    what you would expect when a GPIO interrupt is competing for the s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
    [app.h, board.cpp, event.h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]
2026-09-11 fix: off means off, and stop dithering where it cannot fuse
    Two faults behind "lots of LEDs glitching which should be off" and "still very
    noticeable flicker on low brightness". One was a regression I had just
    introduced; the other is a limit of the technique that was never faced.
    The stray lit LEDs were mine, from the comparator jitter of the last commit. A
    pixel that goes dark while carrying a positive dither error was being pushed
    over the threshold by the jitter and lighting for a frame. Without the jitter
    the residue could sit below the threshold indefinitely without ever firing, so
    the bug arrived with the fix for the other one. Across a panel where pixels go
    dark constantly, that is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
    [main.cpp]
2026-09-11 fix: share the dither across a pixel, and take the unshowable to zero
    The hue drift was the useful symptom. Measured on the accent colour at low
    brightness, 50 frames in 600 had only one of the three channels lit — a
    red-only flash on a pixel that should be steady orange, and never once were all
    three on together.
    Two causes. The channels each had their own jitter, so they crossed the
    threshold on different frames and the pixel spent its time as a sequence of
    partial colours. One jitter per pixel now, shared by all three, so they rise and
    fall together and whatever the pixel does it stays the right hue doing it.
    The other is arithmetic rather than a bug. Gamma turns the accent's blue
    com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
    [main.cpp]
2026-09-11 fix: let the disk finish turning, and floor the brightness where it is measured
    "Where did the radial effect go" has a precise answer: a detent arrives about
    every 150 ms when the knob is being turned and the disk transition takes 420,
    so asking for a new screen on each one restarted the movement before it had
    played a third of itself. The shear that makes it read as a disk never
    appeared, and the panel looked like it was jumping between views. It was there
    all along and never got to happen.
    ScreenManager::retarget changes where a transition is heading without
    restarting it, so a three-click turn is one continuous sweep that lands on the
    third view. And the direction is now the direction yo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
    [app.h]
2026-09-11 fix: make the disk's difference visible, because that is the whole effect
    The transition was running the entire time — progress climbing, the shear in
    the data, tests passing. It just could not be seen, and the reason is
    embarrassing once measured: kDiskClearTurn was set so the rim clears an
    eight-row panel, which is a turn of about 0.3, at which the hub end travels
    1.4 rows. Over four hundred milliseconds that is close enough to motionless
    that most of the panel was simply cross-fading.
    The visible part of a disk turning is the *difference* between the ends. There
    is no difference to see if one end does not move. Making the rim "just clear"
    optimised precisely the wrong quantity.
    So the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
    [framebuffer.h]
2026-09-11 fix: do not read the switch while the knob is turning
    Reported twice: a press firing during a fast turn, and the menu exiting on its
    own. Same cause, and the 15 ms debounce was never going to catch it.
    During a fast turn the rotary contacts make and break continuously, so the
    ground they share with the push switch is disturbed for as long as the turning
    lasts — not for a few milliseconds. No debounce window short enough to keep a
    press feeling instant is long enough to outlast that, which is why raising it
    helped and did not fix it. A dip lasting past 450 ms reads as a hold, and a
    hold is what closes the menu.
    So the switch is not read at all while the knob is moving, for 90 ms after the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
    [event.h, gesture.cpp, gesture.h]
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2026-09-11 fix(net): back the transmit power off, so the radio can associate
    At the default 20 dBm this board could not join anything. The 802.11
    authentication frame went unanswered and timed out after exactly 1000 ms,
    reason 2, on a home router and a phone hotspot alike, while scans saw that
    same network at -32 dBm. Receive perfect, transmit never heard.
    The bisect that settled it: the IDF's own station example, built with none
    of our code, failed identically on this board. So the fault was never in
    this firmware, and every configuration knob turned before this one was
    turned for nothing.
    It is the board. The ESP32-C3 SuperMini pairs a poorly matched onboard
    antenna with a small LDO, and a full-pow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
    [main.cpp]
2026-09-11 fix: a leg per detent, a real clock, and a press that needs a finger
    Three faults reported from the bench, and a fourth found while measuring
    the first three.
    A fast turn appeared to have no animation. retarget() left `from_` alone,
    so a spun knob blended the screen you started on against a destination that
    kept moving; every view in between went unseen and the clock ran out
    mid-sweep. Turning forward and straight back was worse — the destination
    became the screen already being left, and the rest of the transition spent
    itself blending a screen against itself, which is the dead stop that looked
    like a cancelled animation. Each detent is now its own short leg: what was
    arriving becomes wha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
    [app.h, board.cpp, event.h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]
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2026-09-11 fix(encoder): keep the quarter-steps an illegal transition interrupts
    Discarding them was my mitigation for phantom input on a board whose
    encoder pull-ups were unpowered, and it was wrong twice. It never
    addressed that fault — the drift there is slow and produces perfectly
    legal Gray code, so there is no illegal transition to catch it by, and the
    real fix was in the wiring. And at speed an illegal transition does not
    mean noise at all: it means the interrupt missed an edge because the knob
    is being turned hard. Throwing away three quarter-steps there loses a
    detent the user actually turned, exactly when they are spinning fastest.
    Reported as the knob feeling less responsive, which it was.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
    [gesture.h]
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2026-09-11 feat(ui): a settings tree, so the things it remembers can be changed
    Eight settings were written to NVS, migrated and sanitised, and reachable
    by no gesture at all: flip, cycles, auto_next, scene, clock_24h,
    motion_enabled, flat_sleeps and touch_locked. The menu had four entries.
    That is the defect this plan opened with — a readout of a value that
    controls nothing — moved one layer up.
    A setting is now a descriptor rather than a screen: what it is called,
    what it looks like, what kind of value it holds, and an id that one
    get/set pair switches on. Adding one is a row in a table and a case in two
    switches, and the compiler names the switches if you forget. Three levels,
    Menu to Group to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
    [app.h]
2026-09-11 fix(ui): brightness and hue were never stored either
    Found while verifying the settings tree on the board. The Brightness and
    ColorPick screens wrote UiState and never the Settings struct, so both
    were correct until the next power cut and then back to the defaults —
    exactly the fault the tree was built to clear, and the same one TimerSet
    had. It went unnoticed because the defaults are close to what anyone
    picks, so the panel came back looking roughly right.
    Both now write the struct and let apply_settings push it outward, which is
    the one direction the rest of the tree already uses.
    /api/state gains the list position and the setting under the cursor. A
    menu that did not move and one that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
    [main.cpp]
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2026-09-12 fix(isr): the encoder interrupt was reading flash, and OTA proved it
    The first over-the-air update died with a Cache error panic part way
    through the write. The panic address decoded to gpio_get_level, called
    from encoder_isr — an interrupt correctly marked IRAM_ATTR, correctly
    registered with ESP_INTR_FLAG_IRAM, and sitting directly above a comment
    claiming it was "in IRAM, along with everything it touches". It was not.
    Three layers, each hidden behind the one before it, each found only by
    disassembling rather than by reading:
    gpio_get_level lives in flash. Replaced with gpio_ll_get_level, a static
    inline that compiles to a single register read.
    Quadrature::update was still called out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
    [board.cpp, gesture.h]
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2026-09-12 feat(draw): one endpoint for anything a host wants on the panel
    Modelled on Busy Bar's display-element API and trimmed to what 24x8 can
    actually show. One endpoint instead of the half-dozen one-off ones —
    /api/notify, /api/meeting, /api/progress — that this would otherwise have
    grown, each with its own screen and its own lifetime bug.
    Four ingredients: a line of text, a countdown, a named icon, a rail. The
    layout is decided by which ones arrived rather than by a template, because
    there is room for about two and no fixed arrangement fits every pair.
    Text and a countdown take turns. The first version stacked them and they
    collided — the mini font is five rows tall and so is the time fa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
    [app.h, board.cpp]
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2026-09-12 feat(net): a mirror, so the panel can be looked at from somewhere else
    This device has been debugged by photograph three times in one evening —
    a dim travelling pixel, a letter that read as another letter, a rail drawn
    underneath an icon. Each time the fastest available instrument was a phone
    camera pointed at a desk.
    GET /api/screen returns the framebuffer as 192 hex RGB triples and the web
    page draws it into a canvas ten times a second. The first thing it showed
    was FREE, correctly, with the repaired R.
    Hex rather than JSON numbers: 1152 characters against about 1700, a fixed
    length the page can slice without parsing, and no per-pixel object for a
    browser to allocate.
    The framebuffer'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
    [framebuffer.h, main.cpp]
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2026-09-12 feat(ui): give the panel its own network and pairing screens
    The settings tree could navigate and it could set values, and that was
    all it could ever do: every path ended in a screen or a field write, and
    setting_set had no side-effect hook. "Forget every paired host" had
    nowhere to live.
    So SettingKind::Action, dispatched by a switch in App. Not the
    SettingGroup::direct shortcut path, which already carries a hardcoded
    special case for the status picker and does not scale to several
    unrelated destinations.
    The two destructive ones go through a confirm screen first. It shows the
    word and a switch that slides right into red, rather than a question
    above an answer: the mini font is five rows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
    [app.h, board.cpp]
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2026-09-12 feat: erase the device from the knob, and stop setup stalling on the token
    Two things, and the second turned out to explain the first report.
    A factory reset from the panel's own settings, as SYS → RSET. Its own
    group, and last: the neighbour it most resembles is "forget the network",
    and that is exactly why they are kept apart — one costs a Wi-Fi password
    and the other costs every pairing on every host. A group of its own makes
    reaching it a decision rather than an overshoot, and it goes through the
    same confirm, which opens on no.
    That matters more than a convenience. Until now the only way to erase a
    panel was an authenticated POST from a host that was already paired with
    it, so a d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
    [board.cpp]
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2026-09-12 feat: say why a join failed on the panel, and name things properly
    Two follow-ups, and the second is the more useful.
    The panel now shows the refusal. The reason is the whole content: "wrong
    password" and "no such network (2.4 GHz only?)" call for completely
    different next actions, and a panel that only said "failed" would send
    somebody to retype a password that was right. Driven by the reason
    changing rather than by the mode, because a failed join ends where it
    started — back in setup — so the mode is identical before and after. One
    failed join says so once; the next attempt clears it and a second refusal
    is reported as loudly as the first.
    And the labels. LINK, SEEN, CLR, FGET, RSET,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
    [app.h, board.cpp]
2026-09-15 feat(board): the touch pads are fitted
    Three TTP223 modules soldered on GPIO3, 4 and 5, and the encoder soldered
    directly rather than through a breakout. The reader, the pull-downs and
    the whole gesture layer were already there — a web button and a soldered
    pad have always arrived at the recogniser as the same pin levels — so
    what was missing was the declaration that the hardware exists.
    That flag is not ceremony. An unpopulated pin is not a quiet pin: the
    first board read its unwired pads as touched, the recogniser took two of
    them for a chord, and the panel put itself to sleep. A pin that is not
    fitted is never read, which is why this is a constant rather than
    something inferred at ru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
    [board.cpp]
2026-09-15 fix(board): judge a stuck pad by duration, not at boot
    The boot check fired on the first board it ever ran on, for the
    right-hand pad, on hardware whose three pads were all fine — the steady
    state a second later read all of them untouched.
    Startup is the one moment the check cannot be made. A TTP223 calibrates
    itself against its surroundings when it powers up and its output is not
    meaningful until that finishes, about half a second in; the check ran at
    255 ms. A diagnostic that cries wolf is worse than none, because it
    teaches you to ignore the next one.
    Duration is the honest signal. Nobody rests a finger on a panel for
    thirty seconds, so a pad high that long is a fault — an active-lo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
    [board.cpp]
2026-09-15 feat(board): the accelerometer, and it is not an MPU-6050
    The motion layer has been written and tested since the gesture work — a
    knock on the case, a shake, laid flat, picked up, and a TILT group in the
    settings tree to switch them off. What was missing was anything to read.
    `motion_valid` was a hardcoded false.
    So: an MPU on I²C, accelerometer only, read once a frame. The gyro is
    powered but unused; all three gestures fall out of the acceleration
    vector alone.
    The sensor is the one input that can be *asked* whether it is there. A
    floating GPIO cannot be told from a wired one, which is why the fitted
    flags exist at all, but WHO_AM_I either answers or it does not. So
    pins.h declares the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
    [board.cpp, main.cpp]
2026-09-15 docs(wiring): the EC11 common goes to ground, and say so louder
    The encoder went completely dead after being soldered directly: no
    detents, no illegal transitions, all three lines resting high. Three
    separate signal paths failing at once, with board ground testing fine.
    It was one wire. `C` — the common, centre of the three — had gone to
    3V3. The contacts work by pulling a line *down*, so with the common at
    the supply every contact connects its line to the voltage the pull-ups
    already hold it at. Nothing moves. The levels read correct, the resting
    state looks perfect, and every line is dead together.
    The document invited it. The section immediately above the bare-EC11
    table is about th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
    [board.cpp, main.cpp]
2026-09-16 feat(main): measure the things a half-hour fault needs measured
    The last of the three boards starts flickering after about thirty
    minutes — random colour on LEDs the frame says are off. Nothing in the
    firmware could speak to that, so this adds the three readings that can.
    The chip's own temperature, because "it goes wrong after half an hour"
    is a thermal statement and there was no thermometer. Free heap, because
    the other shape of a fault that takes half an hour is something slowly
    running out.
    And dropped frames — which were already happening silently if they were
    happening at all. ws2812_write_async returns an error when a frame
    cannot be queued, or when the previous transfer did not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
    [main.cpp]
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2026-09-16 fix(gesture): a hand reaching over the panel is not a swipe
    Reaching across the panel with a flat left hand changed the view. The
    hand covers all three pads, and as it travels it produces a perfectly
    ordered three-zone sequence with the first zone released by the time the
    third arrives — which is the swipe shape exactly. Order and timing cannot
    tell a hand from a finger. The span can: the outer pads are 95 mm apart
    and a fingertip is not.
    So the test is all three down at once, and only that. A dragged finger
    does brush two adjacent pads in passing — there is a test asserting so,
    and my first attempt at this broke it by rejecting any overlap at all.
    Two is a finger transition; three is a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
    [gesture.cpp, gesture.h]
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2026-09-16 feat: switch the radio off from the knob
    WIFI → USE, and off means off. Useful anywhere Wi-Fi cannot reach the
    panel anyway — an office network with client isolation, where the panel
    joins happily and is unreachable forever — since the radio is then
    costing coexistence airtime on a chip where BLE advertising alone once
    took 35 fps, and buying nothing but the clock.
    The flag is its own NVS key in the shared namespace, exactly as the
    credentials and the tokens already are, and deliberately not a field in
    ui::Settings. That struct is one versioned blob and migrate() refuses any
    version that is not current, with no v1->v2 branch — so adding a bool
    there would reset every existing device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
    [app.h, board.cpp, main.cpp]
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
